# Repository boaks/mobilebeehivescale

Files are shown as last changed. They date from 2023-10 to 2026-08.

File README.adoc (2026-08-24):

// Mobile-Bienenstock-Waage, Version 2.2, Mai 2026

:imagesdir: pictures

= Mobile-Bienenstock-Waage
Achim Kraus <achim.kraus@cloudcoap.net>
v0.6, 2026-05-17

[cols="1*"]
|===
a|.Bienenstöcke mit Waage 
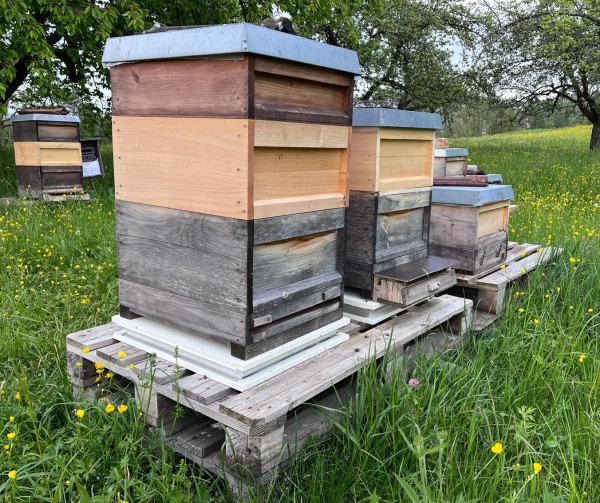
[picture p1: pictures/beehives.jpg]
Bienenstöcke mit Waage

|===

== Willkommen auf meiner Bastelanleitung für eine Mobile-Bienenstock-Waage.

Ich bin einer der IoT-Enthusiasten, der gerne echte und funktionierende Dinge baut. 2022 habe ich angefangen, einen link:https://github.com/boaks/zephyr-coaps-client[Modem-Client] zu implementieren, mit dem man zeigen kann was in link:https://cloudcoap.net[UDP] steckt. In Kombination mit link:https://github.com/eclipse-californium/californium/tree/main/demo-apps/cf-s3-proxy-server[Eclipse/Californium - CoAP-S3-Proxy] demonstriert dieses Beispiel, dass man auch von Batterie ein paar Monate/ein Jahr jede Stunde Daten austauschen kann.   

Anfang 2023 habe ich dann basierend auf diesem Modem-Client meinen erste Bienenstock-Waage gebaut und bei einem befreundeten Imker in Betrieb genommen. Das Ergebnis eines halbjährigen Testlaufs ist einfach: 

* mobiler Datenaustausch funktioniert von Batterie sehr gut
* die Waage selber hat aber viel Verbesserungspotential

Das hat dann zur einer neuen Bauart der Elektronik geführt. Die daraus entstandenen Waagen in link:README-2024.adoc[2024] zeigten dann schon, dass einiges besser ist, aber auch noch weitere Verbesserungen gut wären. Daher habe ich dann Anfang 2025 die Waagen erneut überarbeitet und nach mehreren Monaten testen gibt es nun auch zu diesem Model sehr positive Erfahrungen. Ich möchte trotzdem gleich hier einräumen, dass es genauere Waagen gibt. Mein Schwerpunkt liegt auf dem mobilen Einsatz und dem einfachen Aufbau der Elektronik.

* Es ist für die Handhabung einfacher, wenn die Steuerung/Sendbox direkt in der Waage ist. Dadurch
* gibt es kein "Kabelgewirr" (unpraktisch und teuer),
* kann man die Waagen einfacher mit den Bienenstücken umziehen, 
* bleiben die Kalibrierdaten in der Steuerung bei der Waage, zu der sie gehören.
* die verbleibenden Kabel in der Waage zu den Sensoren sind kurz, das wirkt sich positiv auf die Temperaturabweichung aus.
* Es werden 2x50kg Sensoren verwendet, anstatt 2x100kg. Das hilft nochmal die Temperaturabhängigkeit zu halbieren.
* Der Aufbau der Elektronik wurde stark vereinfacht. Es werden nun Modems verwendet, die über einen QWIIC Anschluß verfügen. So kann man den ADC NAU7802 direkt anschließen. Auch einen Solarladeregler kann man verhältnismässig einfach integrieren.

== Thingy:91X mit 2 Plattform Wägezellen

[cols="3*"]
|===
a|.2025 Waage (keine Kabel mehr!)
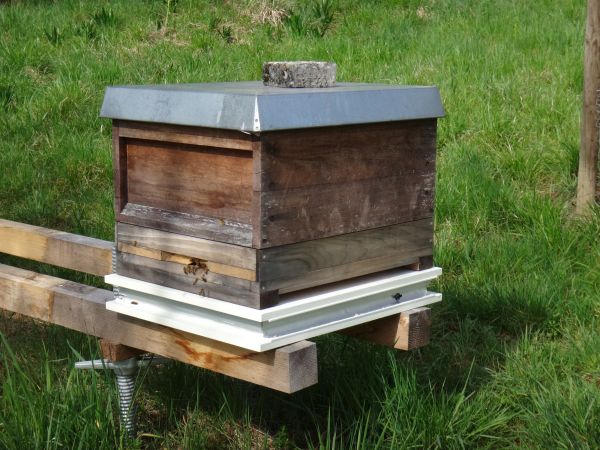
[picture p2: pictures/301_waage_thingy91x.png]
Bienenstock auf 2025 Waage (keine Kabel mehr)
 
a|.Solar-Lader (2x 1 Woche pro Jahr)
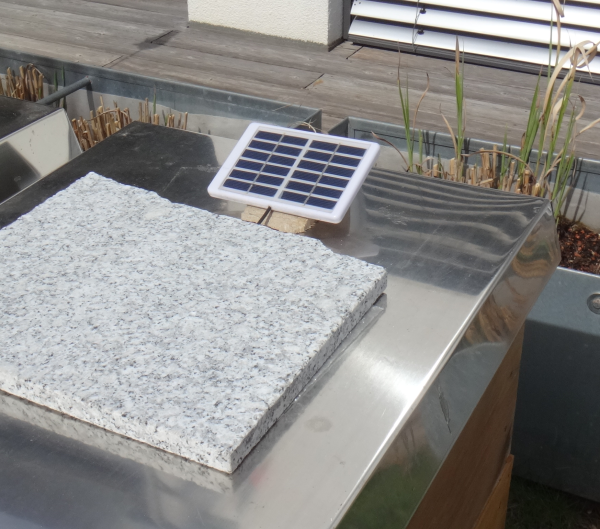
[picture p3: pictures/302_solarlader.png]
Solar-Lader (2x 1 Woche pro Jahr)

a|.Sendebox Thingy:91X und ADC
Sendebox mit Thingy:91X und ADC

a|.2025 Waage, nRF9151-feather
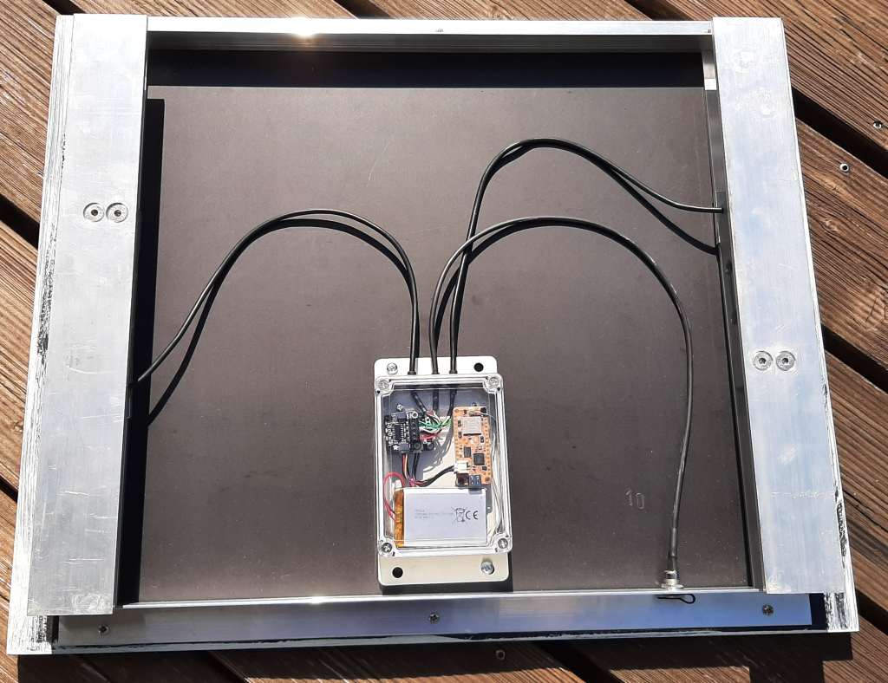
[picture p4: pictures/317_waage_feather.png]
 
a|.Sendbox mit nRF9151-feather
Sendbox mit nRF9151-feather

a|.2025 Waagendeckel für Senkkopfschrauben
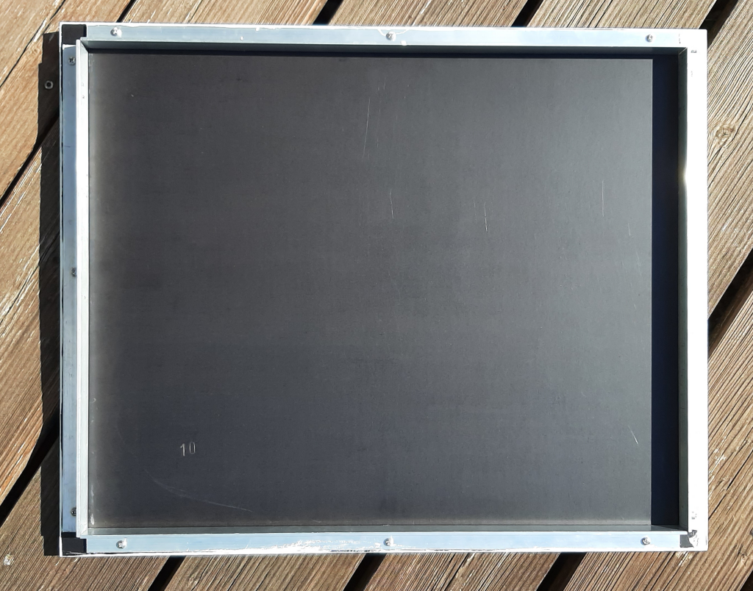
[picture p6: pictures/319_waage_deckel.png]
2025 Waagendeckel für Senkkopfschrauben


a|.Untere Platte mit Aluwinkel 5mm, Wägezellen und Thingy:91X
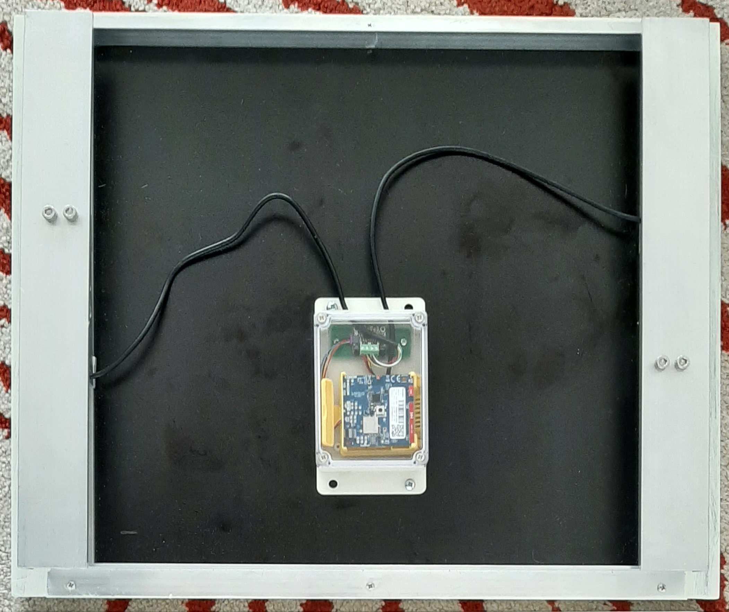
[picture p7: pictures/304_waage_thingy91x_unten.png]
Untere Platte mit Aluwinkel 5mm und Wägezellen montiert und Thingy:91X
 
a|.Schraubenköpfe
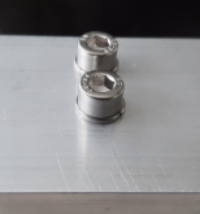
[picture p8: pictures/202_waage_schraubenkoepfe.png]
Schraubenkopf

.Verschraubung mit unterem Brett
Verschraubung 
a|.Obere Platte mit Bohrungen für Schraubenköpfe
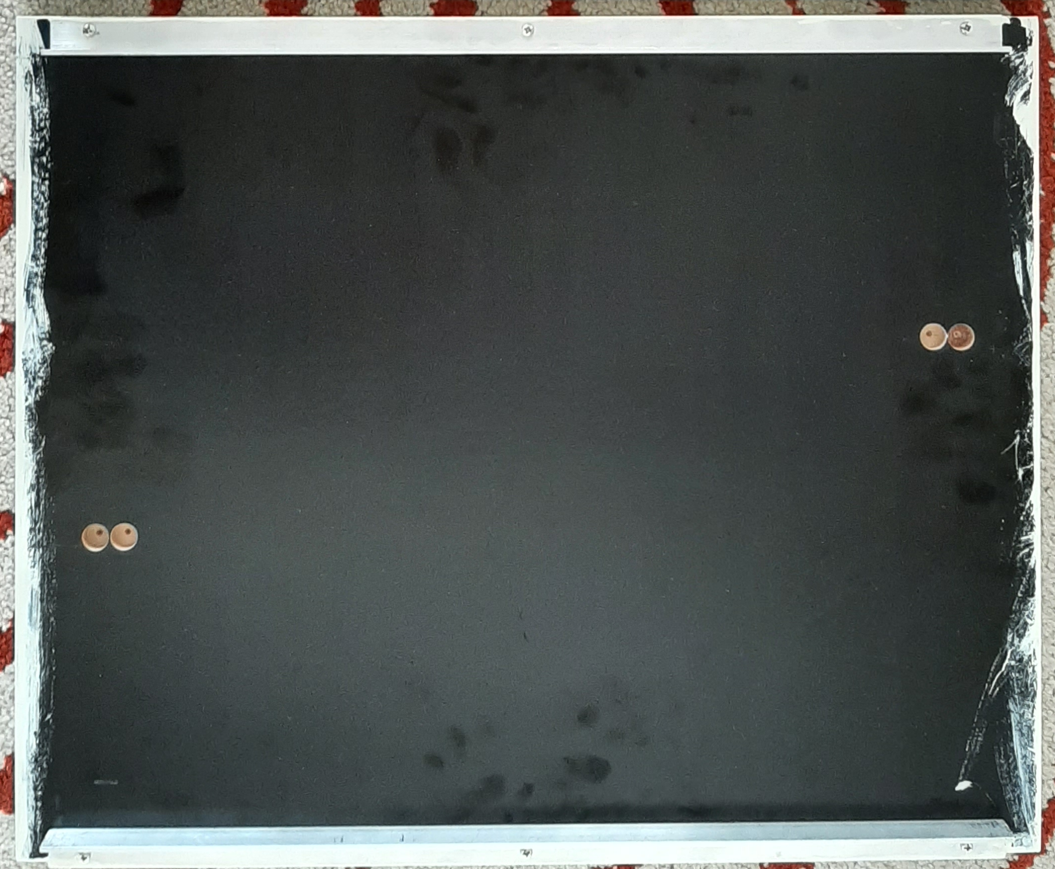
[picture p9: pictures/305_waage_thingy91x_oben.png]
Obere Platte mit Aluwinkel 3mm
 
|===

Die Version 2025 der Mobilen-Bienestock-Waage nutzt nun ein link:https://www.nordicsemi.com/Products/Development-hardware/Nordic-Thingy-91-X[Thingy:91X]. Man schliest den link:https://learn.adafruit.com/adafruit-nau7802-24-bit-adc-stemma-qt-qwiic[ADC NAU7802 von Adafruit] direkt an das Thingy:91X an und beides wandert in die Waage. Damit entfällt einiges an Verkabelung. Die Bedienung läuft über link:https://github.com/boaks/zephyr-coaps-client/blob/main/docu/CELLULAREXPLORER.md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[Bluetooth LE] und man braucht eine link:https://github.com/boaks/zephyr-coaps-client/blob/main/docu/CELLULAREXPLORER.md#smartphone-app[SmartPhone App]. Das ist aber nur für das Kalibrieren notwendig, oder wenn man testen möchte, ob die Sendebox an eimen Aufstellungsort Empfang hat.

Alternativ gibt es auch noch zwei weitere unterstütze Modems mit QWIIC, die link:https://www.circuitdojo.com/products/nrf9151-feather[nRF9151 Feather] und das link:https://conexiotech.com/conexio-stratus-pro-nrf9151/[Conexio Stratus Pro nRF9151], das letztere kommt sogar schon mit einem integrierten Solarladeregler. Beide haben aber keine Bluetooth LE Modul, so dass man ein USB Kabel für das Kalibrieren benötigt.

Der Aufbau mit 2 Plattform Wägezellen gibt der Waage ein besondere Stabilität und Unempfindlichkeit beim Aufsetzen von Lasten. Wichtig ist, dass die Wägezellen sehr schlüssig und stabil mit den starken Aluwinkeln (4mm) verschraubt werden, sonst bekommt man anstatt einer Waage eine Wippe. Die obere Siebdruckplatte wird mit kleineren Aluwinkeln (3mm) gegen verrutschen gesichert. Hier muss man darauf achten, dass diese kleineren Aluwinkel (3mm) nur an den oberen starken Aluwinkeln (4mm) anstoßt. Wenn diese auch am unteren starken Aluwinkeln (4mm) anstossen, verfälscht die Reibung das gemessene Gewicht. Daher sind die oberen zwei starken Aluwinkel (4mm) 40,0cm lang und die unteren zwei mit 39,0cm 10mm kürzer. Die kleineren Aluwinkel (2mm) für die untere Siebdruckplatten schließen den Kasten ab. Diese sind um 16mm kürzer als die oberen kleineren Aluwinkel (3mm).

Für die Schraubenköpfe der M6 Schrauben, die die starken Aluwinkel (4mm) mit der Wägezelle verbinden, muss man in die Siebdruckplatten jeweils Aussparungen bohren (siehe oben, mittleres und rechtes Bild). Die unteren starken Aluwinkeln (4mm) verschraube ich mit den 6mm Senkkopfschrauben und Muttern mit der unteren Siebdruckplatte.

Zwischen die starken Aluwinkeln (4mm) und den Plattform Wägezellen werden noch Distanzplatten benötigt, damit die Wägezelle auslenken kann.

[cols="1*"]
|===
a|.Anordung der Winkel, Distanzplatten und Wägezelle (Alu) 
Anordnung
|===

Die Anordnung der starken Aluwinkel (4mm), der Wägezelle und der Distanzplatten dazwischen habe ich so gewählt, dass der "Aufsetzschutz" (Überlastungsschutz für die Wägezelle), durch die starken Aluwinkel (4mm) selbst gegeben ist. Wichtig sind dabei das Zusammenspiel der Abmessungen. Meine Wägezelle hat eine Höhe von 22mm. Es werden dann oben und unten Distanzplatten benötigt, damit der Sensor auslenken kann. Hier benutze ich jeweils 8mm. Das ergibt dann eine Höhe von 38mm insgesamt. Meine Aluwinkel (4mm) haben eine Innenhöhe von 36mm. Somit ist die Auslenkung auf 2mm begrenzt.

Vielleicht findet der eine oder andere die Anordnung der Winkel seltsam. Ich erreiche damit zum einen nach außen (links) eine möglichst geschlossen Form zu bilden und zum anderen nach innen (rechts) offen zu sein für das Kabel, das aus der Wägezelle kommt und mit der ADC-Platine verbunden werden muss.

Das Zusammenschrauben ist einfach. Man beginnt mit den unteren starken Aluwinkel (4mm), den 8mm Distanzplatten und den Plattform Wägezellen und schraubt diese mit den Zylinderkopfschrauben und Federring fest. Die Wägezelle hat ein Richtung, die durch einen Pfeil angezeigt wird. Wenn man die Schraubenlöcher der Wägezelle benutzt, an der auch das Kabel aus der Wägezelle kommt, dann passt das. Dann schraubt man den oberen starken Aluwinkel (4mm) ebenfalls mit den 8mm Distanzplatten ebenfalls mit Zylinderkopfschrauben fest. Danach setzt man die Kombination auf die untere Siebdruckplatte und verschraubt diese mit den Senkkopfschrauben und Muttern. Ist man damit fertig, dann kann man die dünneren Aluwinkeln (2mm) seitlich ebenfalls auf der unteren Siebdruckplatte montieren. Ich nehme da Spanplattenschrauben 3,5x13mm. Zum Schluß dann noch die 4 schwächeren Aluwinkeln (3mm), oben montieren, ebenfalls mit Spanplattenschrauben.

Da Aluwinkel und Edelstahlschrauben verwendet werden, gibt es bei Nässe Korrosion. Um diese zu reduzieren benutze ich eine Isolierband zwischen den Aluwinkeln und den Siebdruckplatten.   

== Anschlußplan

[cols="3*"]
|===
a|.ADC QWIIC Verbindung 
ADC QWIIC Verbindung


a|.ADC Anschlußplan 
ADC Verkabelung
.Sensorkabel
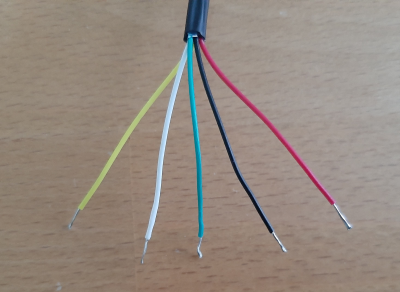
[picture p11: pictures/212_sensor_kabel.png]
Sensorkabel


a|.ADC ohne LED
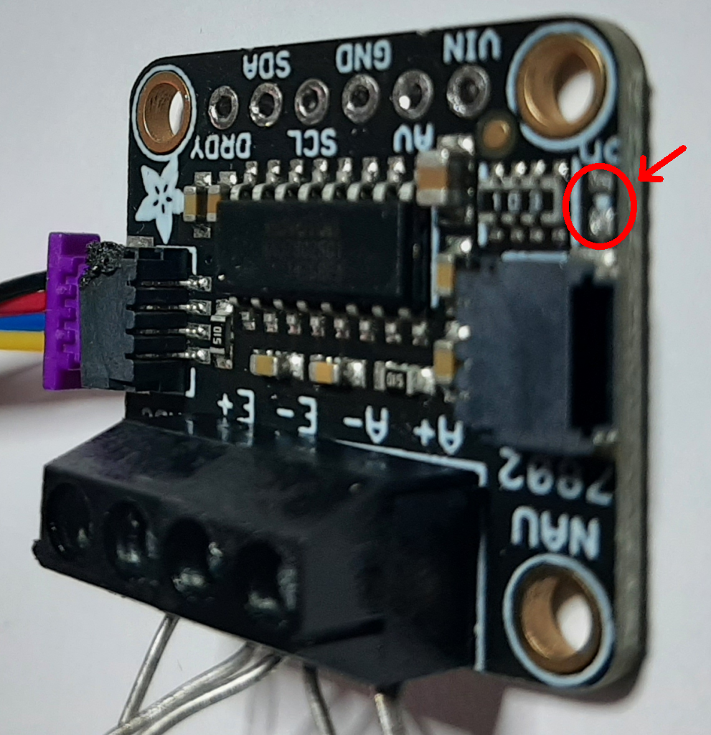
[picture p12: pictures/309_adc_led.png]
ADC ohne Power LED

|===

Der link:https://learn.adafruit.com/adafruit-nau7802-24-bit-adc-stemma-qt-qwiic[ADC NAU7802 von Adafruit] wird direkt mit einem QWIIC Kabel mit dem Thingy:91X verbunden. Auf der Rückseite der NAU7802/Adafruit Platine ist angegeben, wie man die Farben der Leitungen einer Plattform Wägezelle jeweils anschließt. Ich schliese beide Zellen parallel an, d.h. beide roten Leitungen an `E+/Red`, beide schwarzen an `E-/Black`, beide weißen an `A-/White` und beide grünen an `A+/Green`. Das erfordert etwas geschick. "Gelb" ist die Schirmleitung. Da kann man viel dazu im Web lesen. Wenn es passt, klemme ich die mit auf `E-/Black`. Ansonsten "isolieren" und schauen, ob es funktioniert.    

Die Thingy:91X Sendebox schaltet die Stromversorgung für die ADC-Platinen ab. Aktiviert werden die Sensoren dann über den internen Spannungsregler des NAU7802. Dieser liefert gemäß dem Datenblatt maximal 10mA. Für zwei Balkensensoren ist das leider zu wenig. Die brauchen je 6-8mA zusammen also mehr als 10mA. Aktuell betreibe ich solche Waagen außerhalb der Spezifikation des NAU7802. Bis jetzt funktioniert es.

Leider, leider, sind diese ADC Module aus dem Bastel/Hobby-Bereich nicht ganz für den Batteriebetrieb ausgelegt. "Power LEDs" verkürzen die Laufzeit von Batterie erheblich auf ca. 2-3 Monate, auch wenn man das ADC Modul ausschaltet, wenn es nicht benutzt wird. Wenn man die LEDs mit dem Lötkolben entfernt, dann kommt man aber auf gute 8-12 Monate, was zusammen mit zeitweisen Laden über ein Solarpanel dann sehr gut passt.
 
== Bohrpläne

Die Lage der Bohrungen bei den starken Winkeln ergibt sich, wenn der ein Winkelschenkel liegt und der andere noch ober zeigt. 

[cols="1*"]
|===
a|.oberer starker Winkel, 2x 6mm Bohrungen
Bohrplan starker Winkel Oben

a|.unterer starker Winkel, 4x 6mm Bohrungen
Bohrplan starker Winkel Unten

a|.oberer Winkel lang, 3x 3,5mm Bohrungen
Bohrplan Winkel

a|.oberer Winkel kurz, 3x 3,5mm Bohrungen
Bohrplan Winkel

a|.unterer Winkel, 3x 3,5mm Bohrungen (und 1x 11mm)
Bohrplan Aluwinkel

a|.Distanzplatten, 2x 6mm Bohrungen
Bohrplan Distanzplatten

a|.Bretter
Bohrplan Bretter
|===

== Bauteilliste

[cols="4*"]
|===
|Bauteil|Bezugsquelle|Preis (Sommer 2026)|Variante

|Thingy:91X, Nordic, LTE-M/NB-IoT nRF9151 modem  
a|link:https://www.digikey.de/en/products/detail/nordic-semiconductor-asa/THINGY91X/25650019[Thingy:91X, digikey.de]
|112,77 Euro
|Sendbox Thingy

|nRF9151-Feather,Circuit Dojo, LTE-M/NB-IoT nRF9151 modem  
a|link:https://www.digikey.de/de/products/detail/circuit-dojo/PASSY-NRF9151-FEATHER/26580618[nRF9151-Feather, digikey.de]
|69,78 Euro
|Sendbox Feather

|Akku LiPo 2000 mAh  
a|link:https://eckstein-shop.de/LiPo-Akku-Lithium-Ion-Polymer-Batterie-37V-2000mAh-mit-JST-PHR-2-Stecker-LP103450[eckstein-shop]
|7,95 Euro (zzgl. Versand)
|Sendbox Feather

|LTE Antenne  
a|link:https://www.digikey.de/de/products/detail/unictron-technologies-corporation/H2B4MH1F2F0100/9921462[nRF9151-Feather, digikey.de]
|4,42 Euro
|Sendbox Feather

|Adafruit NAU7802 24-BIT ADC, I2C
a|link:https://www.digikey.de/en/products/detail/adafruit-industries-llc/4538/16584123[Adafruit NAU7802, digikey.de]
|6,07 Euro
|Alle

|Adafruit Qwiic Kabel  
a|link:https://www.digikey.de/en/products/detail/adafruit-industries-llc/4210/10230021[Adafruit Qwiic Kabel, digikey.de]
|0,96 Euro
|Alle

|Gehäuse 115x85x35mm, Klarsichtdeckel
a|link:https://www.amazon.de/dp/B0747RGBFF?ref=ppx_yo2ov_dt_b_fed_asin_title[Gehäuse 115x85x35mm, Amazon]
|8,99 Euro
|Alle

|Gehäuse 115x85x35mm, Alternative
a|link:https://www.amazon.de/dp/B0747MHR5B?ref=ppx_yo2ov_dt_b_fed_asin_title[Gehäuse 115x85x35mm, Amazon]
|7,50 Euro
|Alle

|Gummitüllen, T-förmige, 6mm Außen x 4mm Innen x 9mm H, 3 Stück    
a|link:https://www.amazon.de/dp/B0D9K1ZNH4?ref=ppx_yo2ov_dt_b_fed_asin_title[Gummitüllen 6x4x9mm, Amazon]
|7,29 Euro (24 Stück)
|Alle

|Aluwinkel 25x50x4mm, 2x40cm (oben)
a|link:https://www.aluminium-online-shop.de/produkt-kategorie/aluminium-profile/winkel[z.B. Aluminium-Online-Shop]
|11,47 Euro (zzgl. Versand ca. 14 Euro je Bestellung)
|Alle

|Aluwinkel 40x40x4mm, 2x39cm (unten)
a|link:https://www.aluminium-online-shop.de/produkt-kategorie/aluminium-profile/winkel[z.B. Aluminium-Online-Shop]
|10,28 Euro (zzgl. Versand)
|Alle

|Aluwinkel 20x20x3mm, 2x50cm (oben)
a|link:https://www.aluminium-online-shop.de/produkt-kategorie/aluminium-profile/winkel[z.B. Aluminium-Online-Shop]
|5,16 Euro (zzgl. Versand)
|Alle

|Aluwinkel 20x20x3mm, 2x40cm (oben)
a|link:https://www.aluminium-online-shop.de/produkt-kategorie/aluminium-profile/winkel[z.B. Aluminium-Online-Shop]
|4,33 Euro (zzgl. Versand)
|Alle

|Aluwinkel 30x25x2mm, 2x48,4cm (unten)
a|link:https://www.aluminium-online-shop.de/produkt-kategorie/aluminium-profile/winkel[z.B. Aluminium-Online-Shop]
|8,33 Euro (zzgl. Versand)
|Alle

|Aluflachstange 30x8mm, für 4 Distanzplatten a 40mm Länge
a|link:https://www.aluminium-online-shop.de/produkt-kategorie/aluminium-profile/winkel[z.B. Aluminium-Online-Shop]
|5,09 Euro (zzgl. Versand)
|Alle

|Zylinderschrauben A4-80, M6 25mm, 12 Stück
a|link:https://www.schraubenhandel24.de/schrauben/gewindeschrauben/zylinderschrauben/din-912/din-912-zylinderschrauben-isk-edelstahl-a4-80/din-912-zylinderschrauben-edelsta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[z.B. Schraubenhandel24]
|15,95 Euro (200 St, zzgl. Versand)
|Alle

|Federringe A4, M6, 16 Stück
a|link:https://www.schraubenhandel24.de/scheiben/federringe/din-7980/din-7980-federringe-edelstahl-a4/ca-din-7980-a-4-federringe-fuer-zylinderschrauben-6-100st[z.B. Schraubenhandel24]
|5,68 Euro (100 St, zzgl. Versand)
|Alle

|Senkkopfschrauben A2, M6 25mm, 4 Stück
a|link:https://www.schraubenluchs.de/200-Stueck-Senkschrauben-ISO-10642-Edelstahl-A2-M-6x25[z.B. Schraubenluchs]
|6,66 Euro (200 St, zzgl. Versand)
|Alle

|Muttern A2, M6, 4 Stück
a|link:https://www.schraubenluchs.de/200-Stueck-Sechskantmuttern-DIN-934-A2-M6[z.B. Schraubenluchs]
|2,75 Euro (200 St, zzgl. Versand)
|Alle

|Spanplattenschrauben A4, 3,5x13mm, 18 Stück, 
a|link:https://www.schraubenluchs.de/1000-Stueck-Blechschrauben-DIN-7981-A4-35-x-13[z.B. Schraubenluchs]
|13,11 Euro (1000 St, zzgl. Versand)
|Alle

|Spanplattenschrauben A4, 3,5x9,5mm, 18 Stück (alternativ)
|Baumarkt
|7 Euro (50 St)
|Alle

|Plattform Wägezelle E120A 2x 50kg
a|link:https://www.vechta-waagen.com/Single-Point-Waegezelle-E120A-50-kg/VE10080[Wägezelle, Vechta-Waagen, Temperaturkompenstation]
|24,00 Euro (2x, zzgl. Versand)
|Alle

|Plattform Wägezelle CZL601 2x 50kg (alternativ, nicht mehr zu empfehlen)
a|link:https://www.tinkerforge.com/de/shop/load-cell-50kg-czl601.html[Wägezelle, Tinkerforge, Temperaturkompenstation]
|12,99 Euro (2x, zzgl. Versand)
|Alle

|Siebdruckplatten 45x55cm
|Baumarkt
|17 Euro (2x)
|Alle

|Isolierband für Aluwinkel (20mm, 25mm, 35mm)
a|link:https://www.amazon.de/dp/B0D7MGP8JT[Isolierband, Amazon]
|9,75 Euro, 12,95 Euro, 14 Euro (10m, zzgl. Versand)
|Alle

4+a|

'''

|Gesamtsumme
|
a|*260 Euro*
|
|===

(Anmerkung: leider gibt es einige Artikel nur in größeren Packungen und manches nur mit deutlichen Versandkosten. 260 Euro passen nicht, wenn man die Waage einzeln baut.) 

== Bauteilliste Solarlader

[cols="4*"]
|===
|Bauteil|Bezugsquelle|Preis (Sommer 2026)|Variante

|Adafruit BQ25185 Solar charger
a|link:https://www.digikey.de/en/products/detail/adafruit-industries-llc/6091/25805553[Adafruit BQ25185, digikey.de]
|7,10 Euro
|Alle

|Li-Ion Akku ICR18650 3.7V 2200mAh mit JST-PHR-2
a|link:https://eckstein-shop.de/PKNERGY-Lithium-Ion-Battery-ICR-18650-37V-2200mAh-LiPo-Li-Ion-with-JST-PH-Connector[eckstein-shop]
|9,48 Euro
|Sendbox Thingy

|Hohlstecker Buchse
a|link:https://www.amazon.de/dp/B0CMK6XML6[Amazon, 10er Pack]
|6,99 Euro
|Alle

|Anschlußklemme, 3 pol, 2,54 mm 
a|link:https://www.digikey.de/de/products/detail/gct/TBC05-03-1-G-G/26408859[digikey.de]
|0,99 Euro
|Alle

|Micro JST 1.0 SH 3Pin Stecker (nur für Thingy:91X)
a|link:https://www.amazon.de/dp/B0BNCG27CX[Amazon, 5er Pack]
|6,98 Euro
|Sendbox Thingy

|JST Kontakte für Buchse (nur für Thingy:91X), 2x
a|link:https://www.reichelt.de/de/de/shop/produkt/jst_-_crimpkontakt_buchse_-_xh-185091[Platinenstecker, reichelt]
|0,20 
|Sendbox Thingy

|Buchsengehäuse 2pol. (1x für Thingy:91X, 2x für andere Module)
a|link:https://www.reichelt.de/de/de/shop/produkt/jst_-_buchsengehaeuse_1x2-polig_-_xh-185085[Buchse, reichelt]
|0,06
|Alle

|JST Kabel (für andere Module)
a|link:https://www.digikey.de/de/products/detail/jst-sales-america-inc/ASPHSPH24K51/6009457[Kabel, digikey.de]
|0,30 (2x)
|Sendbox Feather

|Solarpanel (abgesetzt, Kunststoff), 6V 1.2W
a|link:https://www.amazon.de/ZONADAH-Hangable-Ladeger%C3%A4t-Projekte-Ladewerkzeuge/dp/B09CM1RJHY[(abgesetzt, Kunststoff), amazon.de]
|6,99 Euro
|Alle

|Solarpanel (abgesetzt, ALU), 5V 1.0W (alternativ)
a|link:https://www.solarversand.de/1-wp-solarmodul-mit-halterung-und-erspiess/[(abgesetzt, ALU), solarversand]
|9,95 Euro
|Alle

4+a|

'''

|Gesamtsumme
|
a|*30 Euro*
|
|===

Auch der Solarladeregler kommt mit einer "Power LED", die weg muss. Hier kommt man um den Lötkolben nicht rum

== Werkzeugliste

[cols="3*"]
|===
|Werkzeug|Bezugsquelle|Preis (Herbst 2025)

|Ständerbohrmaschine
|Sollte man schon haben, sonst wird es teuer 
|

|Spiralbohrer 3,5mm
a|link:https://www.werkzeuge-bohrer.de/bohren-in-metall-und-stahl/geschliffene-bohrer/[werkzeuge-bohrer]
|0,31 Euro

|Spiralbohrer 6mm
a|link:https://www.werkzeuge-bohrer.de/bohren-in-metall-und-stahl/geschliffene-bohrer/[werkzeuge-bohrer]
|0,83 Euro

|Spiralbohrer 8mm
a|link:https://www.werkzeuge-bohrer.de/bohren-in-metall-und-stahl/geschliffene-bohrer/[werkzeuge-bohrer]
|1,34 Euro

|Forstnerbohrer 14mm
a|link:https://www.werkzeuge-bohrer.de/bohren-in-holz/Forstner/Forstnerbohrer-10-mm-shop.html[werkzeuge-bohrer]
|3,55 Euro

|Schaftbohrer 11mm/10mm (Solarladebuchse)
a|link:https://www.werkzeuge-bohrer.de/bohren-in-metall-und-stahl/Bohrer-reduzierter-Schaft/HSS-Bohrer-aehnlich-DIN-338-Typ-NR-Schaft-10-mm.html/[werkzeuge-bohrer]
|8,36 Euro

|Versandkosten
a|link:https://www.werkzeuge-bohrer.de/[werkzeuge-bohrer]
|3,99 Euro

3+a|

'''

|Gesamtsumme
|
a|*18,37 Euro*
|===

== Arbeitszeit

Das hängt natürlich stark von der Bastel-Erfahrung ab. Ich denke, man sollte:

* 1 Nachmittag für Bestellen und Besorgen
* 1 Nachmittag für Bohren (Alu und Siebdruckplatten)
* 1 Nachmittag für Zusammenbauen und Verkabeln
* 1 Nachmittag für Fehlersuche :-)

einplanen.
 
== Software System Overview (English)

link:MobileBeehiveScale.pdf[Mobile-BeeHiveScale]

== Links

link:https://www.youtube.com/watch?v=06RcwLT99Rc[Vorstellung - Eclipse Edge of Things - (English)]

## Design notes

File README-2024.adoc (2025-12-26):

// Mobile-Bienenstock-Waage, Version 2.1, Februar 2025

:imagesdir: pictures

= Mobile-Bienenstock-Waage (2024)
Achim Kraus <achim.kraus@cloudcoap.net>
v0.5, 2025-02-16

[cols="1*"]
|===
a|.Bienenstöcke mit Waage 
Bienenstöcke mit Waage
|===

Es gibt Neuigkeiten für link:README.adoc[2025].

Willkommen auf meiner Bastelanleitung für eine Mobile-Bienenstock-Waage.

Ich bin einer der IoT-Enthusiasten, der gerne echte Dinge baut, die auch funktionieren. 2022 habe ich angefangen, einen link:https://github.com/boaks/zephyr-coaps-client[Modem-Client] zu implementieren, mit dem man zeigen kann was in link:https://cloudcoap.net[UDP] steckt. In Kombination mit link:https://github.com/eclipse-californium/californium/tree/main/demo-apps/cf-s3-proxy-server[Eclipse/Californium - CoAP-S3-Proxy] demonstriert dieses Beispiel, dass man auch von Batterie ein paar Monate jede Stunde Daten austauschen kann.   

Anfang 2023 habe ich dann basierend auf diesem Modem-Client meinen erste Bienenstock-Waage gebaut und bei einem befreundeten Imker in Betrieb genommen. Das Ergebnis des halbjährigen Testlaufs ist einfach: 

* mobiler Datenaustausch funktioniert von Batterie sehr gut
* die Waage selber hat aber viel Verbesserungspotential

Das hat dann zur einer neuen Bauart der Elektronik geführt. Ich möchte gleich hier einräumen, dass es genauere Waagen gibt. Mein Schwerpunkt liegt auf dem mobilen Einsatz und dem Aufbau der Elektronik.

* ADC wandert aus der Sendebox unter die Waage. Kurze Kabel zu den Dehnmesstreifen sind wichtig für eine geringere Temperaturabhängigkeit.
* Kalibrierungsdaten müssen ebenfalls in die Waage. Sonst ist es sehr fehleranfällig, wenn die Waagen umziehen und vertauscht werden. Neu Kalibrieren ist auch einfacher, da man das dann mit jeder Sendbox durchführen kann und nicht die nehmen muss, mit der man dann die Waage im Feld wirklich betreibt.

Die neue Bauart berücksichtigte beides zusammen und läuft nun seit ein Herbst 2023 auf meiner Terrasse und seit Frühjahr 2024 unter Bienenstöcke. Daher möchte ich hier dieses Ergebnis präsentieren, vielleicht hat ja der eine oder andere Interesse, diese Mobile-Bienenstock-Waage nachzubauen. Leider ist aber das Bauen der 2-Kanal-Sendebox doch aufwendig. Seit Winter 2024 gibt es ein neues Gerät von Nordic, das link:https://www.nordicsemi.com/Products/Development-hardware/Nordic-Thingy-91-X[Thingy:91X], welches nun über einen Qwiic (I2C) Port verfügt. Damit kann man den Aufbau drastisch vereinfachen: man steckt den ADC NAU7802 direkt an das Thingy:91X, kein Löten mehr. Verglichen mit der 2-Kanalbox (200 Euro), sind die Kosten mit 130 Euro etwas höher, man braucht ja 2. Wer sich dafür interessiert, liest am besten bei link:T91XDOUBLESCALE.adoc[Waage mit Thingy:91X + NAU7802] weiter. 

Die Ausführung ist ein Kompromis. Manches beruht darauf, was man aus bestehende Komponeten machen kann. Man kann sich da auch alternative Ausführungen vorstellen, aber da bräuchte man dann andere Komponenten oder müßte die selber erstellen. Vielleicht kommt ja die eine oder andere Verbesserung mit der Zeit. 

Links zu den Open Source Projekten:

link:https://github.com/boaks/zephyr-coaps-client[Modem-Client - https://github.com/boaks/zephyr-coaps-client]

link:https://github.com/eclipse-californium/californium/tree/main/demo-apps/cf-s3-proxy-server[Eclipse/Californium - CoAP-S3-Proxy - https://github.com/eclipse-californium/californium/tree/main/demo-apps/cf-s3-proxy-server]

== Bausteine

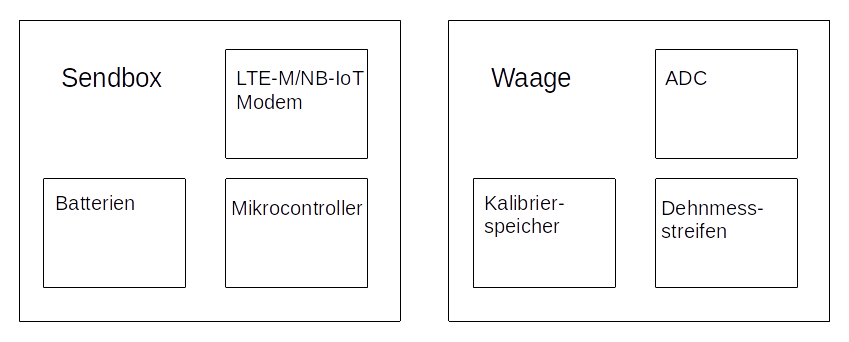
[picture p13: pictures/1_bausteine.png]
Bausteine


Die Mobile-Bienenstock-Waage besteht aus einer `Sendbox` und der `Waage` selbst. 

In der `Sendbox` sind das LTE-M/NB-IoT Modem, der Mikrocontroller und die Batterien untergebracht. Ich benutze ein link:https://www.nordicsemi.com/products/nrf9160[nRF9160] als link:https://www.jaredwolff.com/store/nrf9160-feather/[nRF9160 feather]. Dieses Modem hat als Besonderheit bereits eine Mikrocontroller auf dem Modul, ein ARM Cortec M33 mit 1 mByte Flash und 256 kByte RAM. Als Batterien benutze ich gerne NiMh mit geringer Selbstentladung.

Die Elektronik der `Waage` besteht dann aus einem `ADC`, einem `Speicher für die Kalibrierdaten`, den `Dehnmessstreifen` (als fertige Sensoren). Und natürlich dem mechanischen Aufbau, der aber wie eingangs schon erwähnt, nicht der Schwerpunkt dieser Bastelanleitung ist.

== Der I2C ADC Wandler mit EEPROM

[cols="2*"]
|===
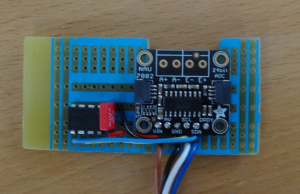
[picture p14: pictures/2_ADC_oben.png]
ADC von oben
a| 
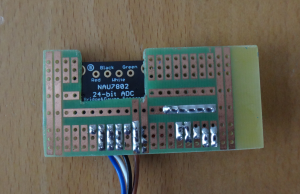
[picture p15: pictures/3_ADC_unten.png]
ADC von unten
a|
|===

Um sowohl den `ADC` als auch den `Kalibrierspeicher` unter die `Waage` zu packen, sollten beide die gleiche Schnittstelle haben. Daher habe ich den geläufigen HX711 gegen einen link:https://www.nuvoton.com/products/smart-home-audio/audio-converters/precision-adc-series/nau7802kgi/[NAU7802] mit link:https://de.wikipedia.org/wiki/I%C2%B2C[I2C] getauscht und ein kleines link:https://www.microchip.com/en-us/product/at24hc04b[AT24HC04B EEPROM], ebenfalls mit `I2C`, hinzugepackt.

Um den NAU7802 nicht selber auf eine Platine packen zu müssen, habe ich ein link:https://learn.adafruit.com/adafruit-nau7802-24-bit-adc-stemma-qt-qwiic[fertiges Modul von Adafruit] benutzt. Das muss dann zusammen mit dem EEPROM auf eine zusätzliche kleine Platine, bei mir passt das auf 5x3cm. Die Verkabelung ist sehr einfach, man muss die Stromversorgung an beide ICs anlegen und die beide I2C Leitungen, SDA und SCL jeweils mit dem anderen IC verbinden. Als Kabel zur Sendebox habe ich ein 4 poliges Kabel, 2m, mit einem 12mm Stecker (eigentlich Buchse) und einem offenen Kabelende genommen, z.B. link:https://www.lutronic.biz/de/konnektivitaet/produkt/1200+...+0[Lutronic M12].

Das link:https://learn.adafruit.com/adafruit-nau7802-24-bit-adc-stemma-qt-qwiic[NAU7802 von Adafruit] hat eine LED die anzeigt, dass die Stromversorgung anliegt. Da sowohl der NAU7802 als auch das EEPROM aber einen sehr geringen Ruhestrom haben, schalte ich den Strom nicht ab. Ich habe daher die LED entfernt, damit diese nicht unnötig den Ruhestrom vergrößert.  

|===
|Beschreibung|NAU7802|AT24HC04B|Kabel Lutronic

|Vcc
|Vin
|Vcc, PIN 8
|Braun

|GND
|GND
|GND, PIN 4
|Schwarz

|SDA
|SDA
|SDA, PIN 5
|Blau

|SCL
|SCL
|SCl, PIN 6
|Weiß
|===

Der Anschluß `AV` (Analog Vin) des NAU7802 wird nicht benutzt, wir benutzen den internen Spannungsregler des NAU7802.

Beim EEPROM bleiben `WP` (Write Protect, PIN 7) soweit `A1` und `A2` (PIN 2 und PIN 3) unbeschaltet bzw. diese können mit `GND` verbunden werden.
Für das EEPROM habe ich den üblichen 0,100 µF Folienkondensator zwischen `GND` und `Vcc` zur Entkopplung benutzt. 

Der DMS Sensor muss dann noch entsprechend mit ``E+``/``E-``/``A+``/``A-`` des NAU7802 verbunden werden. Man kann dazu entweder die beim Adafruit mitgelieferten Schraubklemmen benutzen oder die Leitungen anlöten. Die genau Verdrahtung ist weiter unten in <<die-waage>> beschrieben. Wenn alles gelötet ist sorgfälltig alle Flußmittelreste mit einem Reiniger entfernen. Wenn ich Platinen im Freien nutze, versehe ich diese mit einem Schutzlack. Auch wenn diese natürlich in ein Gehäuse kommt.

Der interne Spannungsregler des NAU7802 liefert gemäß dem Datenblatt maximal 10mA. Das passt für viele Sensoren, nicht aber wenn zwei Balkensensoren verbaut werden. Die brauchen je 6-8mA zusammen also mehr als 10mA. Aktuell betreibe ich solche Waagen außerhalb der Spezifikation des NAU7802. Vielleicht funktioniert es ja, wenn man nur alle Stunde für ein paar Sekunden anschaltet. 

Wenn nicht, braucht man für diesen Fall einen externen Spanungsregler mit `ENable` Eingang, z.B. link:https://www.ti.com/lit/ds/symlink/lp2980-n.pdf[LP2980-N]. `E+` muss dann dort mit den `ENable` (On/OFF PIN 3) verbunden werden und `E+` der Sensoren mit dem Ausgang des Spannungsreglers. Man muss auch die Empfehlungen für zusätzlich Kondensatoren beachten, meist 1µF low ESR und 0,1µF Folienkondensator. Und man muss auch auf eine "low drop" Version achten. `Vcc` beträgt nur 3,3V und am Sensor sollte man 2,7-3,0V haben. Leider ist bei der Adafruit Version der Eingang für `REFP` nicht nutzbar, damit geht dann die ratiometrische Beschaltung des ADC-Boards verloren, wenn man den externen Spanungsregler über `E+` schalten möchte. Die ratiometrische Beschaltung sorgt sonst dafür, dass langsame Abweichungen in der analogen Spannung das Messergebnis nicht beeinflußen.

Die 3,3V Versorgungsspannung ist ein Kompromis. Wenn man auf 5V hoch geht, dann sind die Messergebnisse genauer. Aber dazu muss man aus den Batterien diese zweite 5V Spannung ableiten, und das mit möglichst geringem Ruhestrom. Oder 4 anstatt 3 AA Batterien nehmen. Ich habe mich erst einmal für die einfache Variante mit 3,3V entschieden.

Anmerkung: leider stellte sich raus, dass das link:https://www.microchip.com/en-us/product/at24hc04b[AT24HC04B EEPROM] einen I2C Adress-Konflikt mit dem auf der link:https://www.jaredwolff.com/store/nrf9160-feather/[nRF9160 feather] verbauten Uhrenchip hat. Wenn man die oberen 256 Bytes des EEPROM anspricht, dann wird aus der 0x50 I2C Adresse des EEPROM die 0x51 was aber die des link:https://www.nxp.com/products/analog-and-mixed-signal/real-time-clocks/rtcs-with-ic-bus/tiny-real-time-clock-calendar-with-alarm-function-and-ic-bus:PCF85063A[PCF85063A I2C clock] ist. Daher werden nun nur die unteren 256 Bytes genutzt.

Ich empfehle, die Kabellänge auch nicht länger als 2m (eher kürzer) zu wählen. Ansonsten empfiehlt es sich, die 10k Ohm I2C Pull-up Widerstände des link:https://learn.adafruit.com/adafruit-nau7802-24-bit-adc-stemma-qt-qwiic[NAU7802 Modul von Adafruit] mit zusätzlichen 4,7k Ohm Widerständen auf der Platine zu verringern. Aber auch damit kann man keine 5m betreiben.

== Die Platine der Sendebox

[cols="2*"]
|===
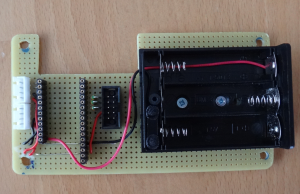
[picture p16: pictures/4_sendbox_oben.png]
Sendbox-Platine von oben
a| 
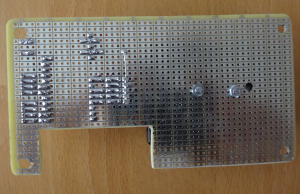
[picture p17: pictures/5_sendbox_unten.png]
Sendbox-Platine von unten
a|
|===

Die zwei Hauptkomponenten, die auf diese Platine müssen, sind die link:https://www.jaredwolff.com/store/nrf9160-feather/[nRF9160 feather] und das Batterienfach, hier 3x AA. Die Verkabelung der Batterei ist trivial und auch die für die link:https://www.jaredwolff.com/store/nrf9160-feather/[nRF9160 feather] ist relativ einfach. Sie besteht aus der Stromversorgung von der Batterie, der Stromversorgung und I2C Bus zu den ADC Platinen, einer RGB LED sowie einem Taster. Die Platine unterstützt bis zu zwei Waagen, jede an einem eigenen I2C Bus (das ist beim NAU7802 leider notwendig). Die beiden I2C sind auf zwei 4 pol. Platinenstecker gelegt. Der Taster und die RGB LED auf einen 10 pol. Pfostenstecker. Die Aussparung in der Platine braucht man, um diese in der Box an der RGB LED und dem Taster vorbei aus- und einbauen zu können. Die verwendete Box hat die Abmessungen 160x80x55mm und erfüllt IP66. Wenn man eine andere Box benutzen möchte, muss man aufpassen, dass die beiden I2C Einbaustecker, die RGB-LED und der Taster entsprechend montiert werden können.

Die Platine muss entsprechend von 160x100mm auf 132x72mm zurecht gesägt werden. Die Aussparung mit 45x20mm wird benötige, da die Platine u.U. bei eingebauter LED und den Taster noch ausgebaut werden muss. Die Bohrungen für die Schrauben haben einen Durchmesser von 4,5mm. Bei den Schrauben muss man auch besonders auf die Länge aufpassen. Bei den Blechschrauben mit Durchmesser 4,2mm ist die Länge 9,5 gängig. Leider sind bei meinem Gehäuse die Bohrungen nur 6mm tief. 2mm für die Platine, dann steht die Schraube 1,5mm über ... das führt zu leicht dazu, dass es ein kleines Loch am Gehäuseboden gibt.

[cols="1*"]
|===
a|.Bohrplan Platine 
Bohrplan
|===

|===
|Beschreibung|nRF9160 feather|Komponente

3+a|*Stromversorgung*

|Vin
|BAT, J2 / PIN 1 
|+ Batterie

|GND
|GND, J3 / PIN 4
|- Batterie

3+a|*I2C Schnitstelle zu ADC-1 über 4 pol. Platinenstecker*

|Vcc
|+3V3, J3 / PIN 2
|ADC 1, Vin, PIN 4

|GND
|GND, J3 / PIN 4
|ADC 1, GND, PIN 3

|SDA 1
|SDA 1, J2 / PIN 12
|ADC 1, PIN 1

|SCL 1
|SCL 1, J2 / PIN 11
|ADC 1, PIN 2

3+a|*I2C Schnitstelle zu ADC-2 über 4 pol. Platinenstecker*

|Vcc
|+3V3, J3 / PIN 2
|ADC 2, Vin, PIN 4

|GND
|GND, J3 / PIN 4
|ADC 2, GND, PIN 3

|SDA 2
|SDA 2, J2 / PIN 7
|ADC 2, PIN 1

|SCL 2
|SCL 2, J2 / PIN 6
|ADC 2, PIN 2

3+a|*10 pol. Pfostenstecker*

|GND
|GND, J3 / PIN 4
|Pfostenstecker, PIN 1,3,5,7,9

|Vcc
|+3V3, J3 / PIN 2
|Pfostenstecker, PIN 4

|Taster
|P0.17, J3 / PIN 9
|Pfostenstecker, PIN 2

|LED Rot
|P0.19, J3 / PIN 11
|Pfostenstecker, PIN 6, 380 Ohm

|LED Blau
|P0.21, J3 / PIN 12
|Pfostenstecker, PIN 8, 380 Ohm

|LED Grün
|P0.22, J3 / PIN 13
|Pfostenstecker, PIN 10, 380 Ohm
|===

Wenn man eine link:https://www.reichelt.de/laborkarte-cem3-rm-2-54-mm-3-loch-loetinseln-re-310-s1-p105479.html[3-Loch-Lötinseln] Platine nimmt, dann ist der Aufbau meist mit einfachen Drahtbrücken zwischen den Lötinseln machbar.

[cols="2,1,1,1"]
|===
|"Löten nach Farben"|Beschreibung|Farbe|Bemerkung

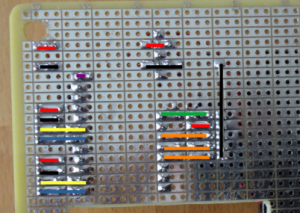
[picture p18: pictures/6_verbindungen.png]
1.7+a|
|Vin
|Lila
|

|GND
|Schwarz
|Auch Oberseite

|Vcc
|Rot
|Auch Oberseite

|SDA
|Blau
|

|SCL
|Gelb
|

|Taster
|Grün
|

|RGB LED
|Orange
|380 Ohm
|===

Die I2C Signalleitungen sind einfache Drahtbrücken zwischen 4 pol. Platinenstecker und Feather. Ebenso die Verbindung für den Taster zum 10 pol. Pfostenstecker. Die Verbindung für die LEDs zum 10 pol. Pfostenstecker und Feather macht man am einfachsten mit den 380 Ohm Vorwiderständen. Die Kabel des Batterienhalter kann auch man einfach mit der Feather verbinden. Mit `Vcc` und `GND` ist es nicht ganz so einfach, da müssen die Inseln auch auf der Oberseite der Platine entsprechend verbunden werden. Ich habe dazu meist farbige Kabellitzen benutzt. Nur für `GND` zum 10 pol. Pfostenstecker auf der Unterseite habe ich auch Draht genommen. 

Die RGB LED und der Taster werden dann über ein Flachkabel angelötet und über eine Pfostenbuchse angesteckt. Dabei wird der Taster mit `GND` und `PIN 2` verbunden. Die gemeinsame Anode (+) der RGB LED wird mit `PIN 4` verbunden, die jeweiligen Farb-Kathoden mit `PIN 6`, `PIN 8` und `PIN 10`. Das fertige Kabel kann man weiter unten bei <<die-sendebox>> sehen.

Die zwei externen I2C Busse direkt an der nRF9160 Feather anzuschließen ist auch ein Kompromis. Ein zusätzlicher link:https://www.sparkfun.com/products/16784[I2C Multiplexer] wäre hier ein bessere Lösung aber man muss da noch einiges in der Software anpassen und testen, so das ich mich ebenfalls für die einfachere Ausführung ohne diesen `I2C Multiplexer` entschieden habe. 

== Die Waage

ifdef::env-github[]
[cols="2*"]
|===
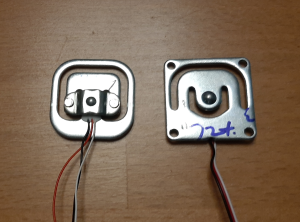
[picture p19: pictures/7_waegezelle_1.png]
Einfache Wägezelle
a| 
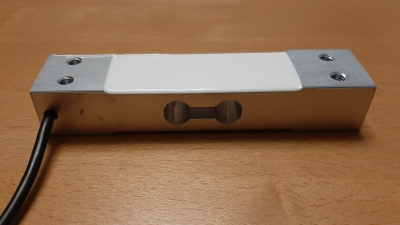
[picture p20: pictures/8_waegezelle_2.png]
Plattform Wägezelle
a| 
|===
endif::[]

ifndef::env-github[]
[cols="2*"]
|===
a|Einfache Wägezelle 
a|Plattform Wägezelle 
|===
endif::[]

Waagen kann man auf unterschiedlichste Weisen bauen. Man findet dazu auf den entsprechenden Internetseiten viele Anregungen.

Ich selber habe mich mit zwei Bauarten versucht:

Links eine sehr link:SIMPLESCALE.adoc[einfache Waage] mit 4x Halbbrücken Wägezellen für je 50Kg. Diese Wägezellen werden normalerweise für Personenwaagen benutzt. Insgesamt ein kosten günstiger Einstieg, mit begrenzter Haltbarkeit und das Gewicht ist deutlich Temperaturabhängigkeit.

Rechts eine link:DOUBLESCALE.adoc[aufwendigere Waage] mit 2x Plattform Wägezellen für je 100Kg. Der Aufbau ist aufwendiger und deutlich teurer, liefert dafür das genauere Gewicht, besonders im Bezug auf die Temperaturabhängigkeit der Wägezellen.
  
== Das Modem

[cols="2*"]
|===
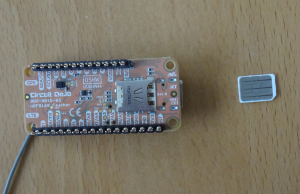
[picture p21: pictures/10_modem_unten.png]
Modem von unten
a| 
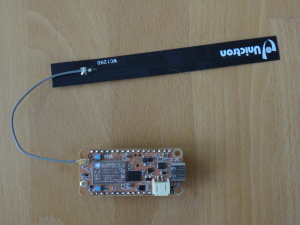
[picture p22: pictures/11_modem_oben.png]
Modem von oben
a| 
|===

Wie eingangs schon erwähnt, die Besonderheit dieses link:https://www.nordicsemi.com/products/nrf9160[nRF9160 Modems] ist, dass es bereits eine Mikrocontroller enthält. Damit spart man sich viel Bastelarbeit. Und als link:https://www.jaredwolff.com/store/nrf9160-feather/[nRF9160 feather] geht das Basteln leicht von der Hand. Für den Mobilfunk benötigt man dann ein SIM-Karte. Normale SIM-Karten sind nicht für LTE-M oder NB-IoT freigeschalten, man muss entsprechende IoT SIM-Karten benutzen. Leider sind diese oft nur für Gewerbebetreibende erhältlich. Die Kosten reichen von 1 Euro pro Jahr über 70 Cent pro Monat bis auch 5 Euro pro Monat. Das hängt ganz vom Anbieter ab. Die Waage mit link:https://www.rfc-editor.org/rfc/rfc7252.html[CoAP] / link:https://www.rfc-editor.org/rfc/rfc6347.html[DTLS 1.2] link:https://www.rfc-editor.org/rfc/rfc9146.html[CID] benötigt sehr wenig Datenvolumen. Wenn man das Gewicht von 2 Waagen alle Stunde sendet sind das ca. 700 kByte im Monat. Viel der Karten bieten 50 MByte pro jahr an und kommen dann damit locker hin. Die 3 AA 2000mAh Akkus halten 6-12 Monate. Das hängt von vielen Faktoren ab, auch wie die SIM-Karten vom Provider konfiguriert sind und welche Netze erlaubt sind.

Das Modem unterstützt auch andere Protokolle, z.B. `HTTP(S)` oder `MQTT(S)`. Je nach Sende-Strategie benötigen diese deutlich mehr Energie oder übertragen die Daten sehr viel seltener (z.B. 1x Täglich nicht 1x Stündlich). Ich benutze diese daher nicht. Wer selber programmieren kann, kann das aber sehr gerne ausprobieren. 

Man kann die Daten auch weiterleiten, das link:https://github.com/eclipse-californium/californium/tree/main/demo-apps/cf-s3-proxy-server[Eclipse/Californium - CoAP-S3-Proxy] leited diese z.B in einen `S3` Cloudservice weiter. Die aktuelle Web-Browser App liest die Daten dann dort aus und stellt diese als Chart dar.

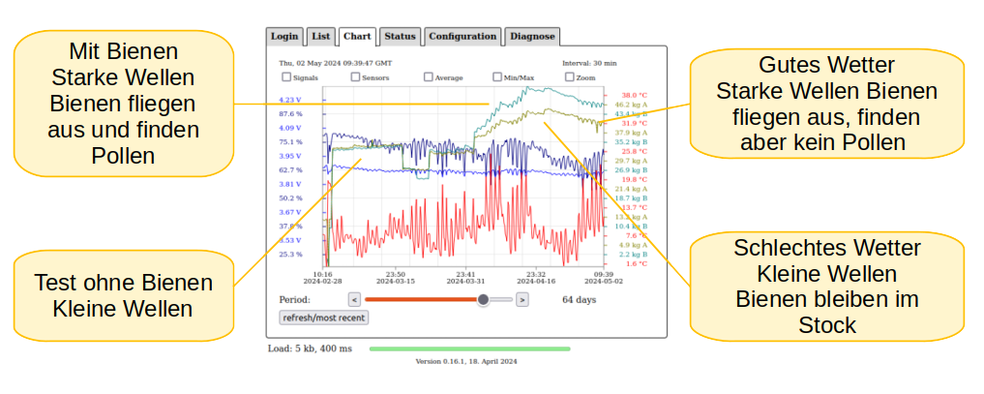
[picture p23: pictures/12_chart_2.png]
Chart im Web-Browser
  

Man muss klar erwähnen, dass es auch bei LTE-M und NB-IoT Funklöcher gibt, also Orte, wo der Empfang schlecht ist oder kein Empfang möglich ist. Wenn man sich die Enttäuschung die Waage vergeblich aufzustellen sparen will, kann mit einem link:https://www.nordicsemi.com/Products/Development-hardware/Nordic-Thingy-91[Thingy:91] und einem Android Smart Phone auch vorab testen, ob man Empfang hat und welche Signalstärke man bekommt. Dazu habe ich ebenfalls ein Programm entwickelt, den link:https://github.com/boaks/zephyr-coaps-client/blob/main/docu/CELLULAREXPLORER.md[Cellular Explorer] mit dem man die Netzwerklandschaft erkunden kann.
 
Der Applikations Mikrocontroller des nRF9160 wird in C programmmiert. Das Embedded Betriebssystem ist link:https://www.zephyrproject.org/[Zephyr]. Die Applikation für die Waage findet man in meinem link:https://github.com/boaks/zephyr-coaps-client[Zephyr - CoAPs Demo Client]. Näheres zur Konfiguration kann man dann dort in link:https://github.com/boaks/zephyr-coaps-client/blob/main/docu/MOBILEBEEHIVESCALE.md/[Mobile-Beehive-Scale]. Die Applikation ist bzgl. der Waage eher eine Entwicklungsversion als eine stabile Release.

Die Bedienung und Anzeige ist relativ einfach.

|===
|Aktion|Funktion 

2+a|*Normalbetrieb*

|Taster kurz drücken und loslassen ( < 5s)
|Gewichte mit der Waagen ermitteln und senden. +
Die LED wird blau und dann hellblau. Sobald sie grün wird hat das Modem Empfang. Blinkt es danach rot, trat ein Fehler auf. Blinkt es lila sucht das Modem ein Funknetzwerk. 

|Taster lang drücken ( > 5s)
|Setupbetrieb

2+a|*Setupbetrieb*
2+|Die Farbe wechselt alle 5s zwischen Grün und Blau

|Taste bei Grün kurz drücken ( < 5s)
|Kalibrierbetrieb

|Taste bei Blau kurz drücken ( < 5s)
|Sendbox neu starten

|Taste lange drücken ( > 5s)
|Setupbetrieb verlassen, in den Normalbetrieb wechseln 

2+a|*Kalibrierbetrieb*
2+|Die Kalibrierung erfolgt in 6 Schritten.
|LED blink grün|Vorbereitung beide Waage für die 0kg-Punkt Kalibrierung
|LED grün|Beide Waage kalibrieren den 0kg-Punkt
|LED blink blau|Vorbereitung Waage 1 für die 10kg Kalibrierung 
|LED blau|Waage 1 kalibriert 10kg
|LED blink hellblau|Vorbereitung Waage 2 für die 10kg Kalibrierung
|LED hellblau|Waage 2 kalibriert 10kg
2+|Ist Waage 1 oder 2 nicht angeschlossen, entfällt der Schritt.

2+|In den Vorbereitungsschritten mit blinkender LED wartet die
Applikation auf einen Tastendruck um dann die jeweilige Kalibrierung durchzuführen.

|Taste kurz drücken ( < 5s)
|Kalibrierung duchführen. +
Wechsel zum nächsten Vorbereitungschritt. Am Ende speichern und in den Normalbetrieb wechseln 

|Taste lang drücken ( > 5s)
|Kalibrierung abbrechen, speichern und in den Normalbetrieb wechseln 
|===

== Die Sendebox

[cols="3*"]
|===
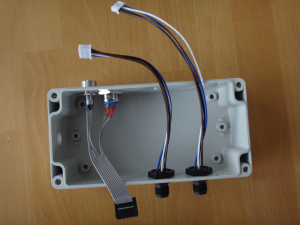
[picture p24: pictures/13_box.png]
Sendebox leer
a| 
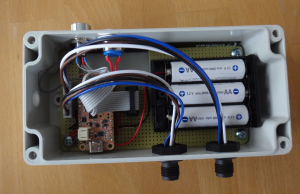
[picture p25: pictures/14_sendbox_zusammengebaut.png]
Sendbox zusammengebaut
a|
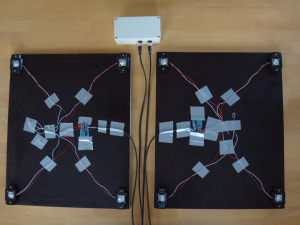
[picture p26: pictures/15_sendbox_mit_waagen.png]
Sendbox mit Waagen
a|
|===

Das erste Bild zeigt die leere Sendebox mit den 2 Kabeln für die ADCs/I2C und dem entsprechenden Einbaustecker für die 12mm Kabel. Das Flachbandkabel für die RGB-LED und den Taster sieht man ebenso. Im zweiten Bild sieht man, wie es aussieht, wenn die Platine, das Modem und die Sendbox zusammengebaut sind. Beim Battereienfach ist es besser eines mit Deckel zu nehmen. Den muss man dann noch schließen bevor man den Deckel der Box ebenfalls schließt. Das letzte Bild zeigt dann, wie zwei Waagen angeschloßen werden.

Wenn man das 160x80x55mm Gehäuse aus der <<Bauteilliste>> nimmt, und auch die Stecker, den Taster und das LED Gehäuse, dann benötigt man 2x 16mm Bohrungen für die Stecker, 1x 16mm für den Taster und 1x 8mm für das LED Gehäuse.

[cols="2*"]
|===
a|.Bohrplan Vorderseite LED und Taster 
Bohrplan

a|.Bohrplan Rückseite für Stecker 
Bohrplan

|===

Die 16mm Bohrungen waren für mich die schwersten. Ich habe mit einem Kegelbohrer die besten Ergebnisse. Ich habe den bei 16mm mit einem Filzstift marktiert und dann mit der Ständerbohrmaschine gebohrt. Das letzte kleine bischen habe ich dann mit den Kegelbohrer von der anderen Seite mit Hand aufgebohrt. Damit passen dann die Dichtungen der Stecker und des Taster gut in das Loch.

== Arbeitszeit

Das hängt natürlich stark von der Bastel-Erfahrung ab. Ich denke, man sollte:

* 1 Nachmittag für Bestellen und Besorgen
* 1 Nachmittag für Waage und ADC Platine
* 1 Nachmittag für Sendbox, Platine und Gehäusebearbeitung
* 1 Nachmittag für Fehlersuche :-)

einplanen.
 
== Bauteilliste

Eine Liste mit Vorschlägen für die verwendeten Bauteilen und deren Bezugsquellen habe ich auch erstellt.
Es gibt bei den einzelnen Bauteilen Alternativen und alternative Bezugsquellen.

ifdef::env-github[]
link:BAUTEILLISTE.adoc[Bauteilliste]
endif::[]

ifndef::env-github[]
link:BAUTEILLISTE.html[Bauteilliste]
endif::[]

== Software System Overview (English)

link:MobileBeehiveScale.pdf[Mobile-BeeHiveScale]

== Links

link:https://www.youtube.com/watch?v=06RcwLT99Rc[Vorstellung - Eclipse Edge of Things - (English)]

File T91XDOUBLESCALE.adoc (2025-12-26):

// Mobile-Bienenstock-Waage, Version 2.1, Februar 2025

:imagesdir: pictures

= Mobile-Bienenstock-Waage
Achim Kraus <achim.kraus@cloudcoap.net>
v0.5, 2024-05-07

== Thingy:91X mit 2 Plattform Wägezellen

[cols="3*"]
|===
a|.Thingy:91X Waage (keine Kabel mehr!)
Bienenstock auf Thingy:91X-Waage (keine Kabel mehr) 
a|.Solar-Lader (2x 1 Woche pro Jahr)
Solar-Lader (2x 1 Woche pro Jahr)
a|.Sendebox Thingy:91X
Sendebox mit Thingy:91X

a|.Untere Platte mit Aluwinkel 5mm, Wägezellen und Thingy:91X
Untere Platte mit Aluwinkel 5mm und Wägezellen montiert und Thingy:91X 
a|.Schraubenköpfe
Schraubenkopf Schraubenkopf
.Verschraubung mit unterem Brett
Verschraubung 
a|.Obere Platte mit Bohrungen für Schraubenköpfe
Obere Platte mit Aluwinkel 3mm 
|===

Die neuste Version (2025) der Mobilen-Bienestock-Waage nutzt nun ein link:https://www.nordicsemi.com/Products/Development-hardware/Nordic-Thingy-91-X[Thingy:91X] und einen deutlich vereinfachten Aufbau der Elektronik. Man schliest den link:https://learn.adafruit.com/adafruit-nau7802-24-bit-adc-stemma-qt-qwiic[ADC NAU7802 von Adafruit] direct an das Thingy:91X und beides wandert in die Waage. Damit entfallt einiges an Verkabelung. Die Bedienung läuft dann über link:https://github.com/boaks/zephyr-coaps-client/blob/main/docu/CELLULAREXPLORER.md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[Bluetooth LE] und man braucht eine link:https://github.com/boaks/zephyr-coaps-client/blob/main/docu/CELLULAREXPLORER.md#smartphone-app[SmartPhone App]. Das ist aber nur für das Kalibrieren notwendig, oder wenn man testen möchte, ob die Sendebox an eimen Aufstellungsort Empfang hat.

Die Waage ist mit 2x Plattform Wägezellen aufgebaut und entspricht dem vorherigen Model für eine link:DOUBLESCALE.adoc[aufwendigere Waage]. Man kann nur 1 Waage pro Thingy:91X anschließen. Der Aufbau ist leicht modifiziert, damit man 5mm mehr Bauhöhe bekommt. Dazu werden die 2mm und 3mm Distanzplatten durch 2x 5mm Distanzplatten ersetzt. Und der unter starke 5x30x50mm Winkel wird durch einen 5x35x35mm Winkel ersetzt. Es hat sich beim Betrieb mit den dünneren Distanzplatten bei mir eine Anfälligkeit gegen Verschmutzung gezeigt. Mal sehen, ob die 5mm hier auch Abhilfe schaffen. Die alten Waagen waren auch oft mit "überarbeiteten Alu Winkeln" gebaut, weil ich immer mal wieder was geändert oder falsch gemacht habe. Die neuen sind da klarer und bieten daher auch weniger Lücken für Schmutz. Im Herbst wird man sehen, ob sich das gelohnt hat.

Wenn man im Frühling die Waage als Indikator für Pollensuchende Bienen einsetzen möchte, dann ist die Temperaturabhängigkeit relevant. Man hat da zwischen kalten Nächten und sonnigen Tagen schnell 20-30°C Unterschied. Daher benutze ich nun 2x50kg anstatt 2x100kg Sensoren, da ist die Temperaturdrift ebenfalls nur halb so groß.

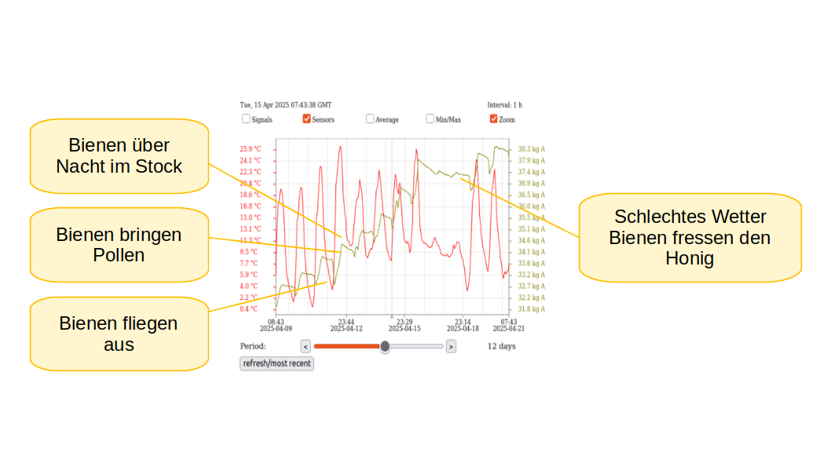
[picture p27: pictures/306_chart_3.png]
Chart im Web-Browser
  

Der Aufbau mit 2 Plattform Wägezellen gibt der Waage ein besondere Stabilität und Unempfindlichkeit beim Aufsetzen von Lasten. Wichtig ist, dass die Wägezellen sehr schlüssig und stabil mit den starken Aluwinkeln (5mm) verschraubt werden, sonst bekommt man anstatt einer Waage eine Wippe. Die obere Platte wird mit kleineren Aluwinkeln (3mm) gegen verrutschen gesichert. Hier muss man darauf achten, dass diese kleineren Aluwinkel (3mm) nur an den oberen starken Aluwinkeln (5mm) anstoßt. Wenn diese auch am unteren starken Aluwinkeln (5mm) anstossen, verfälscht die Reibung das gemessene Gewicht. Daher sind die oberen zwei starken Aluwinkel (5mm) 40,8cm lang und die unteren zwei mit 39,8cm 1cm kürzer. Die kleineren Aluwinkel (3mm) für die untere Platte schließen den Kasten ab. Diese sind um 16mm kürzer als die oberen kleineren Aluwinkel (3mm).

Für die Schraubenköpfe der M6 Schrauben, die die starken Aluwinkel (5mm) mit der Wägezelle verbinden, muss man in die Platten jeweils Aussparungen bohren (siehe oben, mittleres und rechtes Bild). Die unteren starken Aluwinkeln (5mm) verschraube ich ebenfalls mit den 6mm Schrauben und einer Einschlagmutter mit dem unteren Brett.

Zwischen die starken Aluwinkeln (5mm) und den Plattform Wägezellen werden noch Distanzplatten benötigt, damit die Wägezelle auslenken kann.

[cols="1*"]
|===
a|.Anordung der Winkel, Distanzplatten und Wägezelle (Alu) 
Anordnung
|===

Die Anordnung der starken Aluwinkel (5mm), der Wägezelle und der Distanzplatten dazwischen habe ich so gewählt, dass der "Aufsetzschutz" (Überlastungsschutz für die Wägezelle), durch die starken Aluwinkel (5mm) selbst gegeben ist. Wichtig sind dabei das Zusammenspiel der Abmessungen. Meine Wägezelle hat eine Höhe von 22mm. Es werden dann oben und unten Distanzplatten benötigt, damit der Sensor auslenken kann. Hier benutze ich jeweils 5mm. Das ergibt dann eine Höhe von 32mm insgesamt. Meine Aluwinkel haben eine Innenhöhe von 30mm. Somit is die Auslenkung auf 2mm begrenzt.

Vielleicht findet der eine oder andere die Anordnung der Winkel seltsam. Ich erreiche damit zum einen nach außen (links) eine möglichst geschlossen Form zu bilden und zum anderen nach innen (rechts) offen zu sein für das Kabel, das aus der Wägezelle kommt und mit der ADC-Platine verbunden werden muss.

Beim Zusammenschrauben muss man auf die richtige Reihenfolge achten, sonst verdeckt ein Aluwinkel die nächste Schraube. Man beginnt mit den unteren starken Aluwinkel (5mm), den 5mm Distanzplatten und den Plattform Wägezellen. Dann setzt man die zusammengeschraubte Kombination auf das untere Brett und schraubt diese ebenfalls fest. Danach setzt man den oberen starken Aluwinkel (5mm) auf und schraubt diese ebenfalls fest. Ist man damit fertig, dann kann man die kleineren Aluwinkeln (3mm) seitlich, oben und unten montieren. Ich nehme da Spanplattenschrauben 3,5x9,5mm.

== Anschlußplan

[cols="2*"]
|===
a|.ADC Verkabelung 
ADC Verkabelung

a|.Sensorkabel 
Sensorkabel
|===

Von der link:./#der-i2c-adc-wandler-mit-eeprom[i2c ADC-Platine] wird nur der link:https://learn.adafruit.com/adafruit-nau7802-24-bit-adc-stemma-qt-qwiic[ADC NAU7802 von Adafruit] benötigt. Als Kalibrierspeicher wird das Thingy:91X selbst benutzt. Das ist nun fest mit der Waage verbunden. Damit ist die Zuordnung auch fest. Auf der Rückseite der NAU7802/Adafruit Platine ist angegeben, wie man die Farben der Leitungen einer Plattform Wägezelle jeweils anschließt. Ich schliese beide Zellen parallel an, d.h. beide roten Leitungen an `E+/Red`, beide schwarzen an `E-/Black`, beide weißen an `A-/White` und beide grünen an `A+/Green`. Das erfordert etwas geschick. "Gelb" ist die Schirmleitung. Da kann man viel dazu im Web lesen. Wenn es passt, klemme ich die mit auf `E-/Black`. Ansonsten "isolieren" und schauen, ob es funktioniert.    

Die Thingy:91X Sendebox schaltet die Stromversorgung für die ADC-Platinen im Unterschied zu der 2 Kanal-Sendbox ab. Aktiviert werden die Sensoren dann über den internen Spannungsregler des NAU7802. Dieser liefert gemäß dem Datenblatt maximal 10mA. Für zwei Balkensensoren ist das leider zu wenig. Die brauchen je 6-8mA zusammen also mehr als 10mA. Aktuell betreibe ich solche Waagen außerhalb der Spezifikation des NAU7802. Bis jetzt funktioniert es.
 
== Bohrpläne

Die Lage der Bohrungen bei den starken Winkeln ergibt sich, wenn der ein Winkelschenkel liegt und der andere noch ober zeigt. 

[cols="1*"]
|===
a|.oberer starker Winkel, 2x 6mm Bohrungen
Bohrplan starker Winkel Oben

a|.unterer starker Winkel, 4x 6mm Bohrungen
Bohrplan starker Winkel Unten

a|.oberer Winkel, 3x 3,5mm Bohrungen
Bohrplan Winkel

a|.unterer Winkel, 3x 3,5mm Bohrungen (und 1x 11mm)
Bohrplan Aluwinkel

a|.Distanzplatten, 2x 6mm Bohrunge
Bohrplan Distanzplatten

a|.Bretter
Bohrplan Bretter
|===

== Bauteilliste

[cols="3*"]
|===
|Bauteil|Bezugsquelle|Preis (Frühjahr 2025)

|Thingy:91X, Nordic, LTE-M/NB-IoT nRF9151 modem  
a|link:https://www.digikey.de/en/products/detail/nordic-semiconductor-asa/THINGY91X/25650019[Thingy:91X, digikey.de]
|112,77 Euro

|Adafruit NAU7802 24-BIT ADC, I2C
a|link:https://www.digikey.de/en/products/detail/adafruit-industries-llc/4538/16584123[Adafruit NAU7802, digikey.de]
|6,78 Euro

|Adafruit Qwiic Kabel  
a|link:https://www.digikey.de/en/products/detail/adafruit-industries-llc/4210/10230021[Adafruit Qwiic Kabel, digikey.de]
|1,08 Euro

|Gehäuse 115x85x35mm  
a|link:https://www.amazon.de/dp/B0747RGBFF?ref=ppx_yo2ov_dt_b_fed_asin_title[Gehäuse 115x85x35mm, amazon.de]
|8,99 Euro

|Aluwinkel 25x50x5mm, 2x40,8cm (oben)
a|link:https://www.aluminium-online-shop.de/produkt-kategorie/aluminium-profile/winkel[z.B. Aluminium-Online-Shop]
|11,16 Euro (zzgl. Versand ca. 14 Euro je Bestellung)

|Aluwinkel 35x35x5mm, 2x39,8cm (unten)
a|link:https://www.aluminium-online-shop.de/produkt-kategorie/aluminium-profile/winkel[z.B. Aluminium-Online-Shop]
|10,78 Euro (zzgl. Versand)

|Aluwinkel 20x20x3mm, 2x50cm (oben)
a|link:https://www.aluminium-online-shop.de/produkt-kategorie/aluminium-profile/winkel[z.B. Aluminium-Online-Shop]
|5,07 Euro (zzgl. Versand)

|Aluwinkel 25x25x3mm, 2x48,4cm (unten)
a|link:https://www.aluminium-online-shop.de/produkt-kategorie/aluminium-profile/winkel[z.B. Aluminium-Online-Shop]
|6,14 Euro (zzgl. Versand)

|Aluflachstange 30x5mm, für 4 Distanzplatten a 30mm Länge
a|link:https://www.aluminium-online-shop.de/produkt-kategorie/aluminium-profile/winkel[z.B. Aluminium-Online-Shop]
|2,62 Euro (zzgl. Versand)

|Zylinderschrauben A4-80, M6 20mm, 12 Stück
a|link:https://www.schraubenhandel24.de/schrauben/gewindeschrauben/zylinderschrauben/din-912/din-912-zylinderschrauben-isk-edelstahl-a4-80/din-912-zylinderschrauben-edelsta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[z.B. Schraubenhandel24.de]
|22,61 Euro (200 St, zzgl. Versand)

|Federringe A4, M6, 12 Stück
a|link:https://www.schraubenhandel24.de/scheiben/federringe/din-7980/din-7980-federringe-edelstahl-a4/ca-din-7980-a-4-federringe-fuer-zylinderschrauben-6-100st[z.B. Schraubenhandel24.de]
|5,68 Euro (100 St, zzgl. Versand)

|Einschlagmuttern A2, M6 9mm, 4 Stück
a|link:https://www.schraubenluchs.de/Einschlagmuttern-Edelstahl-A2[z.B. Schraubenluchs]
|1,08 Euro (zzgl. Versand)

|Spanplattenschrauben A4, 3,5x9, 5mm, 12 Stück
|Baumarkt
|7 Euro (50 St)

|Plattform Wägezelle E120A 2x 50kg
a|link:https://www.vechta-waagen.com/shop/produkt/single-point-waegezelle-e120a/[Wägezelle, Vechta-Waagen, Temperaturkompenstation]
|24,00 Euro (2x, zzgl. Versand)

|Plattform Wägezelle CZL601 2x 50kg (alternativ)
a|link:https://www.tinkerforge.com/de/shop/load-cell-50kg-czl601.html[Wägezelle, Tinkerforge, Temperaturkompenstation]
|12,99 Euro (2x, zzgl. Versand)

|Siebdruckplatten 45x55cm
|Baumarkt
|17 Euro (2x)

3+a|

'''

|Gesamtsumme
|
a|*260 Euro*
|===

(Anmerkung: leider gibt es einige Artikel nur in größeren Packungen und manches nur mit deutlichen Versandkosten. 260 Euro passen nicht, wenn man die Waage einzeln baut.) 

== Bauteilliste Solarlader

[cols="3*"]
|===
|Bauteil|Bezugsquelle|Preis (Frühjahr 2025)

|Adafruit BQ25185 Solar charger
a|link:https://www.digikey.de/en/products/detail/adafruit-industries-llc/6091/25805553[Adafruit BQ25185, digikey.de]
|6,41 Euro

|Li-Ion Akku ICR18650 3.7V 2200mAh mit JST-PHR-2
a|link:https://eckstein-shop.de/PKNERGY-Lithium-Ion-Battery-ICR-18650-37V-2200mAh-LiPo-Li-Ion-with-JST-PH-Connector[eckstein-shop.de]
|9,48 Euro

|Hohlstecker Buchse
a|link:https://www.amazon.de/dp/B0CMK6XML6[Amazon, 10er Pack]
|6,99 Euro

|Micro JST 1.0 SH 3Pin Stecker
a|link:https://www.amazon.de/dp/B0BNCG27CX[Amazon, 5er Pack]
|6,98 Euro

|Stiftleiste 2pol. abgewinkelt
a|link:https://www.reichelt.de/de/de/shop/produkt/jst_-_stiftleiste_90_1x2-polig_-_xh-185079[Platinenstecker, reichelt.de]
|0,23

|Buchsengehäuse 2pol.
a|link:https://www.reichelt.de/de/de/shop/produkt/jst_-_buchsengehaeuse_1x2-polig_-_xh-185085[Buchse, reichelt.de]
|0,06

|JST Kontakte für Buchse
a|link:https://www.reichelt.de/de/de/shop/produkt/jst_-_crimpkontakt_buchse_-_xh-185091[Platinenstecker, reichelt.de]
|0,10 (2x)

|Solarpanel (abgesetzt), 6V 1.2W
a|link:https://www.amazon.de/ZONADAH-Hangable-Ladeger%C3%A4t-Projekte-Ladewerkzeuge/dp/B09CM1RJHY[(abgesetzt), amazon.de]
|6,99 Euro

3+a|

'''

|Gesamtsumme
|
a|*25 Euro*
|===

== Bauteilliste, Winkel in V2A Edelstahl

[cols="3*"]
|===
|Bauteil|Bezugsquelle|Preis (Frühjahr 2025)

|Edelstahlwinkel 25x50x4mm, 2x40,8cm (oben, alternativ)
a|link:https://www.stahl-shop24.de/edelstahl/edelstahl-winkel/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[z.B. Stahl-Shop 24]
|37,93 Euro (zzgl. Versand 8,20 Euro je Bestellung)

|Edelstahlwinkel 35x35x4mm, 2x39,8cm (unten, alternativ)
a|link:https://www.stahl-shop24.de/edelstahl/edelstahl-winkel/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[z.B. Stahl-Shop 24]
|17,32 Euro (zzgl. Versand)

|Edelstahlwinkel 20x20x3mm, 2x50cm (oben, alternativ)
a|link:https://www.stahl-shop24.de/edelstahl/edelstahl-winkel/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[z.B. Stahl-Shop 24]
|7,42 (zzgl. Versand)

|Edelstahlwinkel 25x25x3mm, 2x48,4cm (unten, alternativ)
a|link:https://www.stahl-shop24.de/edelstahl/edelstahl-winkel/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[z.B. Stahl-Shop 24]
|9,90 (zzgl. Versand)

|Aluflachstange 30x5mm, für 2 Distanzplatten a 30mm Länge
a|link:https://www.aluminium-online-shop.de/produkt-kategorie/aluminium-profile/winkel[z.B. Aluminium-Online-Shop]
|2,62 Euro (zzgl. Versand)

|Aluflachstange 30x6mm, für 2 Distanzplatten a 30mm Länge
a|link:https://www.aluminium-online-shop.de/produkt-kategorie/aluminium-profile/winkel[z.B. Aluminium-Online-Shop]
|2,62 Euro (zzgl. Versand)

3+a|

'''

|Aufpreis
|
a|*40 Euro*
|===

[cols="1*"]
|===
a|.Anordung der Winkel, Distanzplatten und Wägezelle (Edelstahl)
Anordnung
|===

Die starken Edelstahlwinkel sind mit 4mm 1mm dünner, daher muss eine der Distanzplatten 1mm mehr habe und hat so 6mm. 
Edelstahl ist sehr viel stabiler, besonders wenn man 4mm Winkel sägen möchte, kommt man schnell an die Grenzen. Im Gegensatz zu Aluminium ist fertig abglänger Edelstahl nochmal teurer.

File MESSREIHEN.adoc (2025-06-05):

// Mobile-Bienenstock-Waage, Version 2.0, März 2024

:imagesdir: pictures

= Mobile-Bienenstock-Waage, Messreihen
Achim Kraus <achim.kraus@cloudcoap.net>
v0.1, 2023-12-05

Waagen bauen stellt sich dann doch als nicht so einfach raus. Viele Komponenten sind für andere Anwendungen gedacht. Normale Waage, z.B. Personen-Waagen werden meist nur für eine kurzen Zeitraum belastet. Und meist bei sehr ähnlichen Temperaturen. Eine Bienenstockwaage wird aber über lange Zeit belastet und im Freien sind die Temperaturschwankungen erheblich.
  
## Wägezellen
  
Der erste Faktor, die Abweichung bei Dauerbelastung, wird `Creep` genannt. Die Temperaturanweichung wird in eine 0-Punktverschieben und eine Faktorveränderung angegeben.

[cols="4*"]
|===
|Wägezelle|Creep|Temp. 0-Punkt|Temp. Faktor

||%F.S/30min|%F.S/10°C|%F.S/10°C

|CK-50-Y4 4x50kg|0,05|0,05|0,05

|CZL601 100kg|0,019|0,019|0,016

|Vechta E120A 100kg|0,015|0,017|0,016

|Vechta E30A 200kg|0,016|0,018|0,018

|Mavin NA1 50kg|0,02|0,03|0,02
|===

`%F.S` steht dabei für "Full-Scale" also Vollausschlag. z.B. bei 100kg und 0,05% ergibt das 50g.

Gemäß dem Datenblättern sind die Plattform Wägezelle besser und geeignet und liegen dicht beieinander. Die Plattform Wägezelle haben meistens bereits eine Temperatur-Kompensation und sind deshalb deutlich weniger Empfindlich gegenüber Temperaturschwankungen.

Das spiegelt letztlich den Anwendungsfall und die Kostenoptimierung wieder. Wenn eine Personenwaage kurz vor dem Wiegen auf 0 gestellt wird, dann fallen Creep und die 0-Punktverschiebeung nicht ins "Gewicht". Bei einer Bienenstockwaage bedeutet dies dann, dass man das Gewicht mit dem des Vortages bei in etwas selber Temperatur vergleichen kann und so eine Entwicklung ablesen kann. Für mehr braucht es dann eben die besser geeigneten Plattformsensoren.

Wenn man die Sensoren auswählt, muss man sich auch zwischen der maximal zulässigen Last und der Temperaturabweichung entscheiden, 50kg Sensor hat nur die halbe Temperaturabweichung als die 100kg Variante. 

Außer diesen Faktoren spielt auch noch die Erregerspannung eine Rolle. Die Ausgangsspannung, mit der man dann das Gewicht bestimmen kann, hängt eben von dieser Erregerspannung ab. Deshalb ist es gannz wichtig, dass diese Erregerspannung auch die Referenzspannung des ADC ist, sonst bekommt man hier schnell Fehler. Bleibt, dass man mit einer höheren Erregerspannung im Allgemeinen eine höhere Auflösung bekommen würde. Aber für eine Waage die mit Batterien betrieben wird, muss man da Kompromisse eingehen. 

Meine `Mobile-Bienenstock-Waage` benutzt eine Systemspannung von 3,3V. Als analoge Erregerspannung leite ich davon 2,7V ab, indem ich den ADC (NAU7802) entsprechend konfiguriere.

## ADC

Auch die Präzision des ADC hängt von einigen Faktoren ab. Die gängigen ADC für Waagen bieten meist eine Auflösung von bis zu 24 Bit an. Wenn man aber die Referenzspannung und den gewählten Verstärkungsfaktor hinzunimmt, dann geht diese Auflösung rasch runter. Bei dem benutzten NAU7802 kann man das der Tabelle 1.5.2 auf Seite 10 des Datenblatt entnehmen. Bei 3,3V und Verstärkungsfaktor (gain) 64 bleiben 17 Bit.

Der NAU7802 weißt eine geringe Temperaturabhängigkeit auf, die im Verhältnis zu der der Sensoren in der Praxis aber vernachlässigbar erscheint. Was man aber vor jeder Messung machen sollte ist den 0-Punkt kalibirieren. Dazu hat der NAU7802 eine interne Kalibrierungsfunktion und alternativ die Möglichkeit, die Analogeingänge intern zu verbinden. Ich nutze den 2. Ansatz, da man da selber filtern kann, wann die Werte stabil genung sind. 

## Messreihen

Zu Begin hatte ich den Plan, hier diverse Messreichen aufzuführen. Aber zumindest bei meinen Tests stellte sich raus, dass man sich da ganz schön einfach selber täuschen kann. Siehe meine Beiträge in link:https://community.hiveeyes.org/t/diskussion-zum-nuvoton-nau7802-24bit-2ch-adc/3237/25[Hiveeyes - Diskussion zum Nuvoton NAU7802 24bit 2ch ADC].

Es gibt auch Messreihen von anderen, z.B. link:https://community.hiveeyes.org/t/strain-gauge-load-cell-tests-in-a-diy-climate-chamber/1642/20[Hiveeyes,Strain gauge load cell tests in a DIY climate chamber] oder link:https://beelogger.de/sensoren/waegezellen_hx711/stockwaage-temperaturkompensation/[beelogger - Temperaturkompensation].

Beides spiegelt meine Erfahrungen mit systematischeren Messungen diese Frühjahr (2025) wieder. Bei manchen Sensoren sieht man einen linearen Zusammenhang mit der Temperatur, und eine verbesserte Kompensation ist dann möglich. Bei anderen Sensoren ist das nicht linear. Bis jetzt scheint es für mich auch so zu sein, dass die Varianz zwischen den Sensoren eines Herstellers groß ist, und ich keinen Hersteller gefunden habe, der da eine geringere Varianz oder generell eine geringere Tempeaturabweichung hat.

Messungen mit 8 facher Verstärkung:
 
[cols="3*"]
|===
a|.100kg (Widerstände)
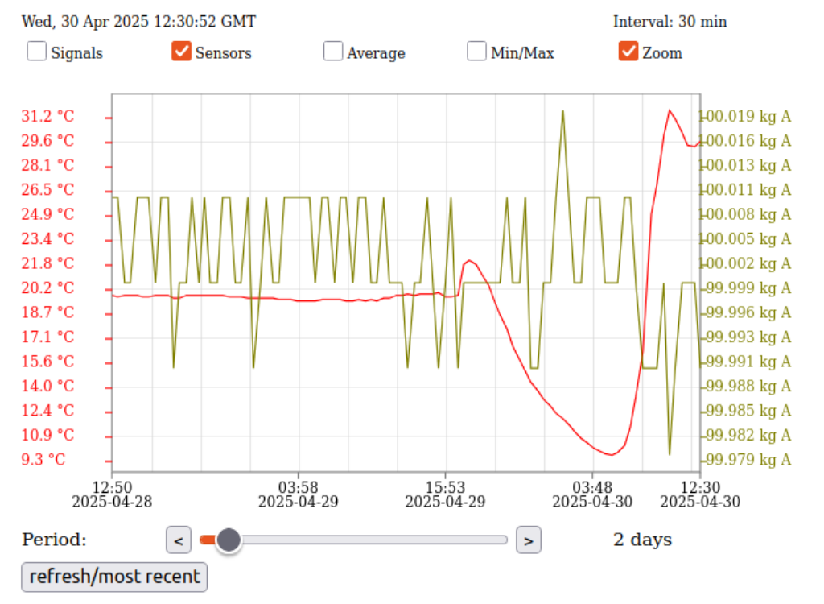
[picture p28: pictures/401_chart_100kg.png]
100kg (Widerstände)
 
a|.0kg (2x50kg Wägezellen)
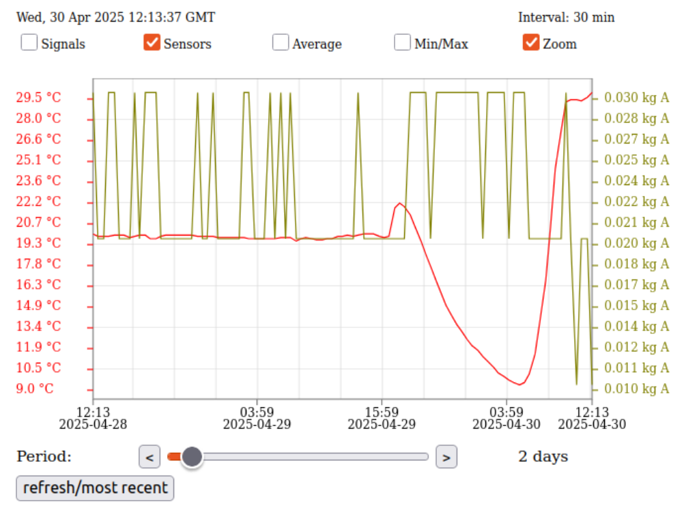
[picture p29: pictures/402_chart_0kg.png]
0kg (2x50kg Wägezellen)

a|.10kg (2x50kg Wägezellen)
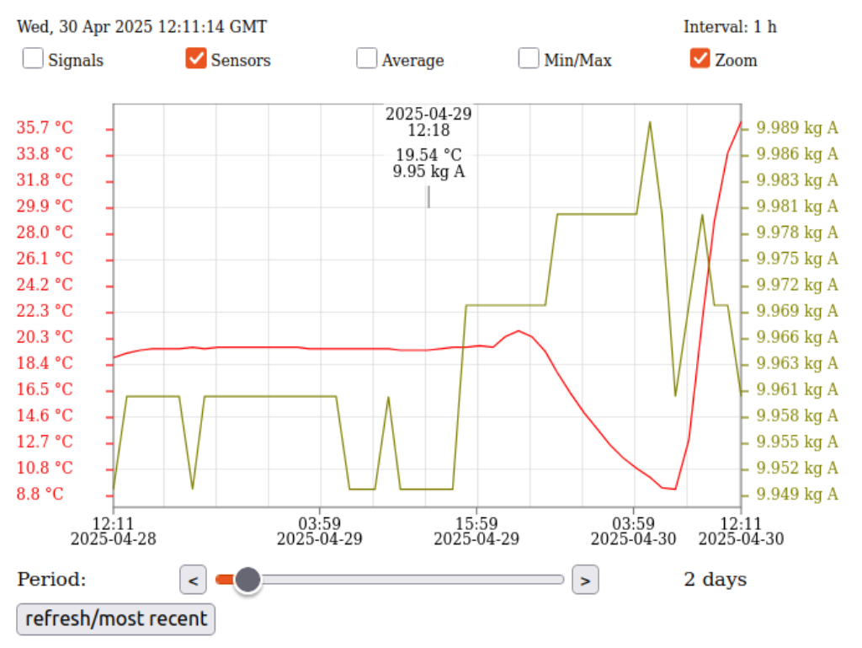
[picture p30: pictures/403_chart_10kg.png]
10kg (2x50kg Wägezellen)

|===

Messungen mit 32 facher Verstärkung, unterschiedliche Sensoren:
 
[cols="3*"]
|===
a|.2x50kg Wägezellen
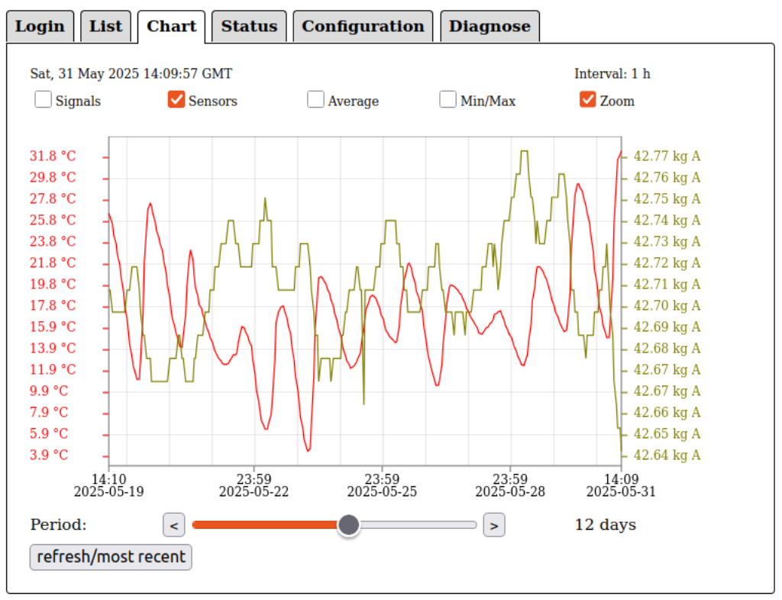
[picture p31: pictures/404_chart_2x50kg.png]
2x50kg Wägezellen
 
a|.2x100 kg Wägezellen
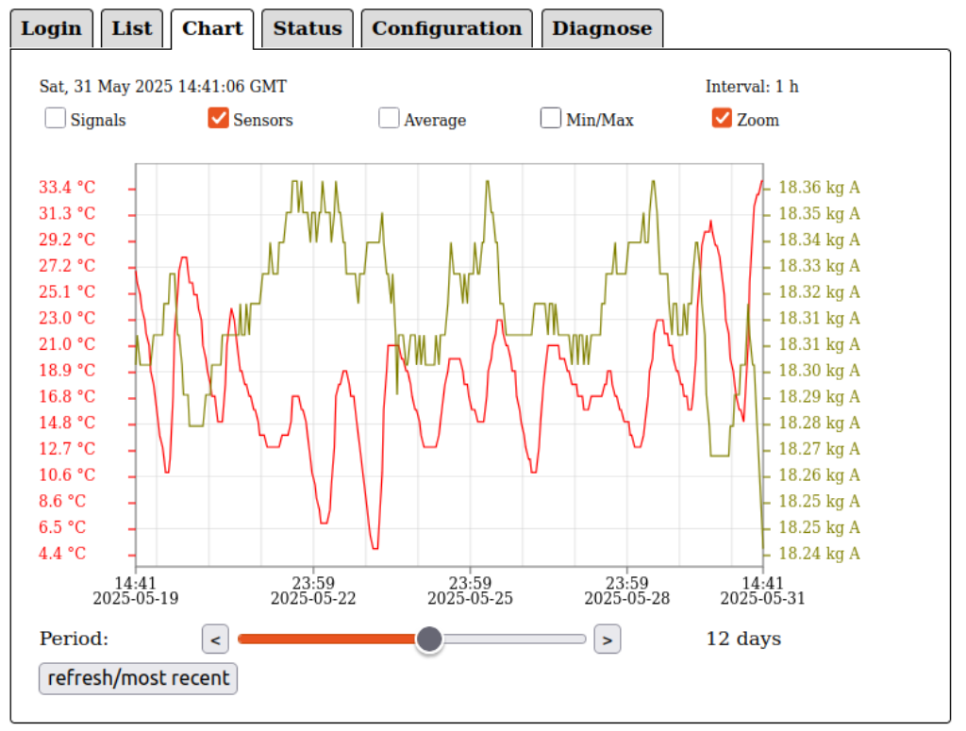
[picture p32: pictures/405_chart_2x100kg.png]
2x100kg Wägezellen

a|.2x100 kg Wägezellen (anderer Hersteller)
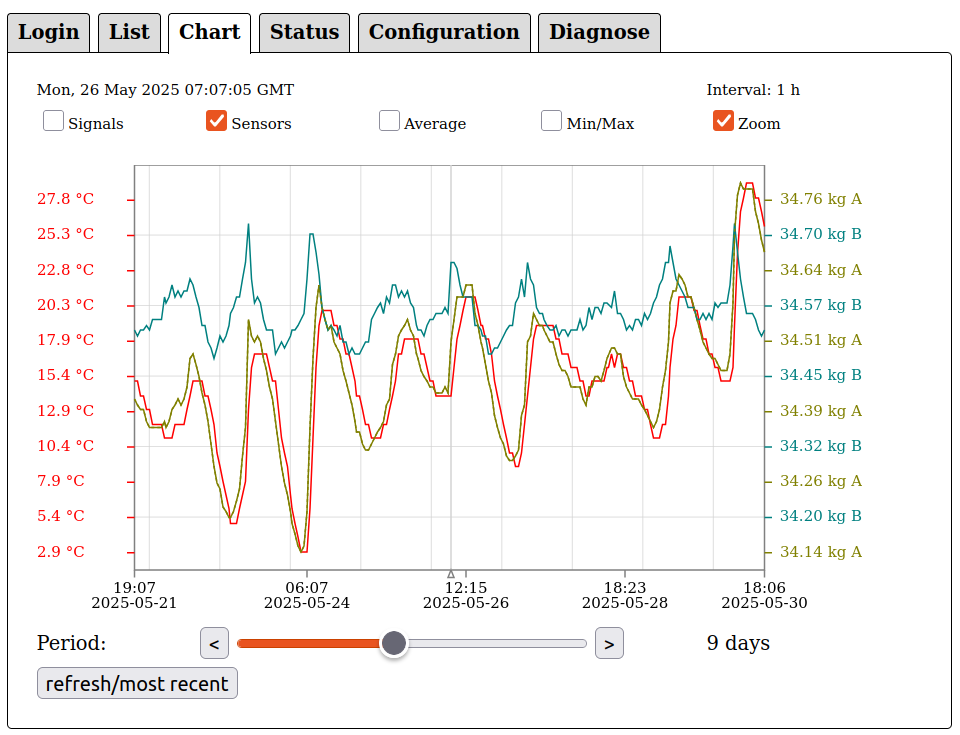
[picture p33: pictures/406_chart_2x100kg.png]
2x100kg Wägezellen)

|===

## Mein Fazit:

2x50kg lieferte bei meinen Test die geringste Temperaturabweichung, die Unterschiede zwischen den Wägezellen (CZL601, Vechta E120A, Mavin NA1) sind gering.
 
Die 2x100kg haben ein höhere Abweichung und bei meinen Tests gab es da dann sehr deutlich "Ausreißer" bei den Wägezellen (CZL601, Vechta E120A). Das Diagramm ganz rechts zeigt zusätzlich mit der "kg B" Kurve an, was eine temperatur-abhängige Kompensation bringen kann. Einschränkend muss erwähnt werden, dass die Temperatur nicht die vom Sensor sondern von der Sendebox ist. Die Kompensationsdaten (Gewichtsabweichung pro °C) muss für jede Waage ermittelt werden.    

Abweichungen bei 30° Temperaturdifferenz:

[cols="3*"]
|===
|Wägezelle|Last <20kg|Last >40kg

|2x50kg|70g|130g

|2x100kg|120g|-

|2x100kg|740g|-

|2x100kg (komp.)|240g|-
|===

Daher erscheint mir die Wahl mit 2x50kg die Beste zu sein.

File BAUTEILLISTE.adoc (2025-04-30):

// Mobile-Bienenstock-Waage, Version 2.0, Mai 2024

:imagesdir: pictures

= Mobile-Bienenstock-Waage, Bauteilliste, Herbst 2024
Achim Kraus <achim.kraus@cloudcoap.net>
v0.4, 2024-10-04

== Bauteilliste, Waage 

[cols="3*"]
|===
|Bauteil|Bezugsquelle|Preis (Herbst 2024)

|Adafruit NAU7802 24-BIT ADC, I2C
a|link:https://www.digikey.de/en/products/detail/adafruit-industries-llc/4538/16584123[Adafruit NAU7802, digikey.de]
|6,78 Euro

|AT24HC04B-PU EEPROM, I2C
a|link:https://www.digikey.de/en/products/detail/microchip-technology/AT24HC04B-PU/1886137[AT24HC04B, digikey.de]
|0,62 Euro

|Folien-Kondensator, 100nF
a|link:https://www.reichelt.de/mks2-pet-kondensator-100-nf-10-63-vdc-rm-5-mks2-63-100n-p12349.html[Folien-Kondensator, reichelt.de]
|0,29 Euro

|Gehäuse, ca 50x50x15mm
a|link:https://www.digikey.de/de/products/detail/bud-industries/CU-18421-B/5291576[Gehäuse, digikey.de]
|3,17 Euro

|Kabel, 2m, 12mm Buchse - offenes Ende
a|link:https://www.reichelt.de/sensorleitung-m12-4-pol-ku-offenes-ende-2-m-lut-1200-004-2-p222963.html[Kabel, reichelt.de]
|8,85 Euro

|Siebdruckplatten 45x55cm
|Baumarkt
|17 Euro (2x)

|Personenwaage Wägezelle 4x 50kg (einfache Waagenausführung)
a|link:https://www.amazon.de/dp/B07HBP1167[Wägezelle, amazon.de]
|10,99 Euro (für 10 Stück, es werden nur 4 benötigt.)

3+a|

'''

|Gesamtsumme je Waage
|Einfache Ausführung
a|*60 Euro*
|===

Der mechanische Aufbau unterscheidet sich je nach Waagentype stark. 

Für den Aufbau mit den einfachen Personenwaagen Sensoren kann man sich Sensorhalter mit einem 3D-Drucker und link:halterung_fuer_waegezellen.stl[Halterung für Wägezellen] erstellen. Der Halter passt für die Sensoren in der Bestellliste und auch für link:https://www.kern-sohn.com/shop/de/produkte/messinstrumente/CK-50-Y4/[Kern CK 50-Y4]. Die Sensoren werden durch den Abstandshalter etwas von der Siebdruckplatten weg gehalten, was die Erwärmung durch Sonne über diese Platten verringert. Die Seite des Abstandshalters mit der Lücke ist für das Kabel vom `Kern CK 50-Y4` Sensor.

== Bauteilliste, Waage mit Plattform Wägezellen 

[cols="3*"]
|===
|Bauteil|Bezugsquelle|Preis (Herbst 2023)

|Gehäuse, ca 80x40x20mm (alternativ)
a|link:https://www.digikey.de/de/products/detail/hammond-manufacturing/1551KFLBK/2094805[Gehäuse, digikey.de]
|3,40 Euro

|Aluwinkel 50x30x5mm, 2x40,0cm (unten)
a|link:https://www.aluminium-online-shop.de/produkt-kategorie/aluminium-profile/winkel[z.B. Aluminium-Online-Shop]
|12,35 Euro (zzgl. Versand ca. 14 Euro je Bestellung)

|Aluwinkel 25x50x5mm, 2x41cm (oben)
a|link:https://www.aluminium-online-shop.de/produkt-kategorie/aluminium-profile/winkel[z.B. Aluminium-Online-Shop]
|12,14 Euro (zzgl. Versand)

|Aluwinkel 20x20x3mm, 2x51cm
a|link:https://www.aluminium-online-shop.de/produkt-kategorie/aluminium-profile/winkel[z.B. Aluminium-Online-Shop]
|5,55 Euro (zzgl. Versand)

|Aluwinkel 20x20x3mm, 2x49,6cm
a|link:https://www.aluminium-online-shop.de/produkt-kategorie/aluminium-profile/winkel[z.B. Aluminium-Online-Shop]
|5,40 Euro (zzgl. Versand)

|Zylinderschrauben A4-80, M6 20mm, 12 Stück
a|link:https://www.schraubenhandel24.de/schrauben/gewindeschrauben/zylinderschrauben/din-912/din-912-zylinderschrauben-isk-edelstahl-a4-80/din-912-zylinderschrauben-edelsta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[z.B. Schraubenhandel24.de]
|22,61 Euro (200 St, zzgl. Versand)

|Federringe A4, M6, 12 Stück
a|link:https://www.schraubenhandel24.de/scheiben/federringe/din-7980/din-7980-federringe-edelstahl-a4/ca-din-7980-a-4-federringe-fuer-zylinderschrauben-6-100st[z.B. Schraubenhandel24.de]
|5,68 Euro (100 St, zzgl. Versand)

|Einschlagmuttern A2, M6 9mm, 4 Stück
a|link:https://www.schraubenluchs.de/Einschlagmuttern-Edelstahl-A2[z.B. Schraubenluchs]
|1,08 Euro (zzgl. Versand)

|Spanplattenschrauben A4, 3,5x9, 5mm, 12 Stück
|Baumarkt
|7 Euro (50 St)

|Plattform Wägezelle CZL601 2x 100kg (alternativ)
a|link:https://www.tinkerforge.com/de/shop/load-cell-100kg-czl601.html[Wägezelle, Tinkerforge, Temperaturkompenstation]
|14,00 Euro (2x)

|Plattform Wägezelle E120A 2x 100kg (alternativ)
a|link:https://www.vechta-waagen.com/shop/produkt/single-point-waegezelle-e120a/[Wägezelle, Vechta-Waagen, Temperaturkompenstation]
|24,00 Euro (2x)

|Plattform Wägezelle H40A 150kg (alternativ)
a|link:https://www.bosche.eu/waagenkomponenten/waegezellen/plattform-waegezellen/plattform-waegezellen-h40a[Wägezelle, Bosche, Test steht aus]
|67,00 Euro

3+a|

'''

|Mehrpreis je Waage
|Plattform Wägezellen Ausführung
a|*80 Euro*
|===

Für den Aufbau mit 2 Plattform Wägezelle, z.B. link:https://www.tinkerforge.com/de/shop/load-cell-100kg-czl601.html[CZL601 100kg], werden Aluwinkel benötigt. Man muss aber auf jeden Fall die maximale Belastung beachten, sonst gehen die Sensoren leicht kaputt (link:https://www.bosche.eu/media/pdf/03/f0/32/Hilfe-bei-der-Auswahl-von-Wa-gezellen-TIPP.pdf[Wägezellen Auswahl]). Der Preis liegt dann, je nach Sensor, pro Waage um 80 Euro und mehr höher.

Mein Fokus liegt auf der Elektronik, daher führe ich weitere Bauarten hier nicht auf. Man findet diese aber leicht im Web.
 
== Bauteilliste, Sendebox

[cols="3*"]
|===
|Bauteil|Bezugsquelle|Preis (Herbst 2023)

1.2+a|nRF9160 Feather
a|link:https://www.circuitdojo.com/products/nrf9160-feather[nRF9160 feather, www.circuitdojo.com]
|99 $ + Importkosten.

a|Alternativ link:https://www.digikey.de/en/products/detail/circuit-dojo/PASSY-NRF9160-FEATHER/13668137[nRF9160 feather, digikey.de]
|105,04 Euro

1.2+a|LTE Antenne
a|link:https://www.circuitdojo.com/products/nrf9160-feather[LTE Antenne, www.circuitdojo.com]
|5$ + Importkosten.

a|Alternativ link:https://www.digikey.de/en/products/detail/unictron-technologies-corporation/H2B4MH1F2F0100/9921462[LTE Antenne, digikey.de]
|4,80 Euro

|Einbaustecker Kunststoff, 50cm, 12mm
a|link:https://www.reichelt.de/einbausteckverbinder-m12-4-pol-stecker-schwarz-lut-1230-04-100-p347094.html[Einbaustecker Kunststoff, reichelt.de]
|4,70 Euro (2x ?)

|Einbaustecker metall, 50cm, 12mm (alternativ)
a|link:https://www.reichelt.de/einbausteckverbinder-m12-4-pol-stecker-0-5-m-lut-1230-t16cw04-p223037.html[Einbaustecker Metall, reichelt.de]
|5,99 Euro (2x ?)

|Schutzkappe für Einbaustecker, 12mm, (falls nur 1 Waage angeschlossen wird)
a|link:https://www.reichelt.de/schutzkappe-m12-stecker-lut-cp0-p223055.html[Schutzkappe, reichelt.de]
|0,60 Euro

|Platinenstecker/Stiftleiste 4pol.
a|link:https://www.reichelt.de/jst-stiftleiste-gerade-1x4-polig-xh-jst-xh4p-st-p185075.html[Platinenstecker, reichelt.de]
|0,23 (2x)

|Platinenstecker/Buchsengehäuse 4pol.
a|link:https://www.reichelt.de/jst-buchsengehaeuse-1x4-polig-xh-jst-xh4p-bu-p185087.html[Buchsengehäuse, reichelt.de]
|0,09 (2x)

|Platinenstecker/Buchse
a|link:https://www.reichelt.de/jst-crimpkontakt-buchse-xh-jst-xh-ckb-p185091.html[Buchse, reichelt.de]
|0,15 (8x)

|Gehäuse, 160x80x55mm
a|link:https://www.reichelt.de/industriegehaeuse-160-x-80-x-55-mm-ip66-lichtgrau-5u320000-p324381.html[Gehäuse, reichelt.de]
|9,20 Euro

|Laborkarte 3-Loch-Lötinseln
a|link:https://www.reichelt.de/laborkarte-cem3-rm-2-54-mm-3-loch-loetinseln-re-310-s1-p105479.html[Laborkarte, reichelt.de]
|6,50 Euro

|Batteriehalter 3xAA mit Deckel
a|link:https://www.reichelt.de/batteriehalter-fuer-3-mignon-aa-geschlossen-halter-3xaa-p44631.html[Batteriehalter, reichelt.de]
|1,35 Euro

|Pfostenstecker, 10 pol.
a|link:https://www.reichelt.de/wannenstecker-10-polig-gerade-wsl-10g-p22816.html[Pfostenstecker, reichelt.de]
|0,13 Euro

|Pfostenbuchse, 10 pol.
a|link:https://www.reichelt.de/pfostenbuchse-10-polig-mit-zugentlastung-pfl-10-p14571.html[Pfostenbuchse, reichelt.de]
|0,10 Euro

|Flachbandkabel, 10 pol.
a|link:https://www.reichelt.de/flachbandkabel-awg28-10-pol-grau-3m-ring-awg-28-10g-3m-p47637.html[Flachbandkabel 3m, reichelt.de]
|3,59 Euro (es werden nur 15cm benutzt)

|Taster
a|link:https://www.voelkner.de/products/73350/TRU-Components-701802-GQ16F-10-J-N-Vandalismusgeschuetzter-Drucktaster-48-V-DC-2A-1-x-Aus-Ein-tastend-IP65-1St..html[Taster, voelkner.de]
|4,99 Euro

|RGB LED
a|link:https://www.voelkner.de/products/1028434/HuiYuan-5039R2G3B2C-ESB-LED-bedrahtet-Rot-Gruen-Blau-Rund-5mm-1900-mcd-2350-mcd-1850-mcd-45-20mA.html[RGB LED, voelkner.de]
|0,75 Euro

|LED Fassung
a|link:https://www.voelkner.de/products/29240/Signal-Construct-SML1089-SML1089-LED-Fassung-Metall-Passend-fuer-LEDs-LED-5mm-Schraubbefestigung.html[LED Fassung, voelkner.de]
|4,49 Euro

|Akkus und Ladegerät, NiMh 2000mAh
a|link:https://www.amazon.de/Panasonic-eneloop-LED-Anzeigen-Sicherheitsfunktionen-Mignon-Akkus-blue/dp/B0B5X4PKW1[Akkus, amazon.de]
|31,99 Euro (es werden nur 3 Stück benutzt)

|SIM-Karte für LTE-M und NB-IoT
|Viele Quellen mit unterschiedlichen Leistungen
|10-30 Euro (reichen 3-10 Jahre)

3+a|

'''

|Gesamtsumme
|
a|*200 Euro*
|===

== Bauteilliste, Thingy:91X + NAU7802

[cols="3*"]
|===
|Bauteil|Bezugsquelle|Preis (Frühjahr 2025)

|Thingy:91X, Nordic, LTE-M/NB-IoT nRF9151 modem  
a|link:https://www.digikey.de/en/products/detail/nordic-semiconductor-asa/THINGY91X/25650019[Thingy:91X, digikey.de]
|112,77 Euro

|Adafruit NAU7802 24-BIT ADC, I2C
a|link:https://www.digikey.de/en/products/detail/adafruit-industries-llc/4538/16584123[Adafruit NAU7802, digikey.de]
|6,78 Euro

|Adafruit Qwiic Kabel  
a|link:https://www.digikey.de/en/products/detail/adafruit-industries-llc/4210/10230021[Adafruit Qwiic Kabel, digikey.de]
|1,08 Euro

|Gehäuse 115x85x35mm  
a|link:https://www.amazon.de/dp/B0747RGBFF?ref=ppx_yo2ov_dt_b_fed_asin_title[Gehäuse 115x85x35mm, amazon.de]
|8,99 Euro

|Aluwinkel 35x35x5mm, 2x40,0cm (unten)
a|link:https://www.aluminium-online-shop.de/produkt-kategorie/aluminium-profile/winkel[z.B. Aluminium-Online-Shop]
|10,78 Euro (zzgl. Versand ca. 14 Euro je Bestellung)

|Aluwinkel 25x50x5mm, 2x41cm (oben)
a|link:https://www.aluminium-online-shop.de/produkt-kategorie/aluminium-profile/winkel[z.B. Aluminium-Online-Shop]
|11,16 Euro (zzgl. Versand)

|Aluwinkel 20x20x3mm, 2x51cm
a|link:https://www.aluminium-online-shop.de/produkt-kategorie/aluminium-profile/winkel[z.B. Aluminium-Online-Shop]
|5,07 Euro (zzgl. Versand)

|Aluwinkel 25x25x3mm, 2x49,6cm
a|link:https://www.aluminium-online-shop.de/produkt-kategorie/aluminium-profile/winkel[z.B. Aluminium-Online-Shop]
|6,14 Euro (zzgl. Versand)

|Aluflachstange 30x5mm, 4x30mm (Distanzplatten)
a|link:https://www.aluminium-online-shop.de/produkt-kategorie/aluminium-profile/winkel[z.B. Aluminium-Online-Shop]
|2,62 Euro (zzgl. Versand)

|Zylinderschrauben A4-80, M6 20mm, 12 Stück
a|link:https://www.schraubenhandel24.de/schrauben/gewindeschrauben/zylinderschrauben/din-912/din-912-zylinderschrauben-isk-edelstahl-a4-80/din-912-zylinderschrauben-edelsta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[z.B. Schraubenhandel24.de]
|22,61 Euro (200 St, zzgl. Versand)

|Federringe A4, M6, 12 Stück
a|link:https://www.schraubenhandel24.de/scheiben/federringe/din-7980/din-7980-federringe-edelstahl-a4/ca-din-7980-a-4-federringe-fuer-zylinderschrauben-6-100st[z.B. Schraubenhandel24.de]
|5,68 Euro (100 St, zzgl. Versand)

|Einschlagmuttern A2, M6 9mm, 4 Stück
a|link:https://www.schraubenluchs.de/Einschlagmuttern-Edelstahl-A2[z.B. Schraubenluchs]
|1,08 Euro (zzgl. Versand)

|Spanplattenschrauben A4, 3,5x9, 5mm, 12 Stück
|Baumarkt
|7 Euro (50 St)

|Plattform Wägezelle E120A 2x 100kg
a|link:https://www.vechta-waagen.com/shop/produkt/single-point-waegezelle-e120a/[Wägezelle, Vechta-Waagen, Temperaturkompenstation]
|24,00 Euro (2x)

|Plattform Wägezelle CZL601 2x 100kg (alternativ)
a|link:https://www.tinkerforge.com/de/shop/load-cell-100kg-czl601.html[Wägezelle, Tinkerforge, Temperaturkompenstation]
|14,00 Euro (2x)

|Siebdruckplatten 45x55cm
|Baumarkt
|17 Euro (2x)

3+a|

'''

|Gesamtsumme
|
a|*260 Euro*

|===

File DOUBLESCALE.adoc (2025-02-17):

// Mobile-Bienenstock-Waage, Version 2.0, Mai 2024

:imagesdir: pictures

= Mobile-Bienenstock-Waage
Achim Kraus <achim.kraus@cloudcoap.net>
v0.3, 2024-05-07

== Waagenaufbau mit 2 Plattform Wägezellen

[cols="3*"]
|===
a|.Untere Platte mit Aluwinkel 5mm und Wägezellen
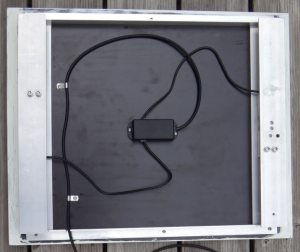
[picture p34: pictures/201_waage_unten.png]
Untere Platte mit Aluwinkel 5mm und Wägezellen montiert
 
a|.Schraubenköpfe
Schraubenkopf Schraubenkopf
.Verschraubung mit unterem Brett
Verschraubung 
a|.Obere Platte mit Bohrungen für Schraubenköpfe
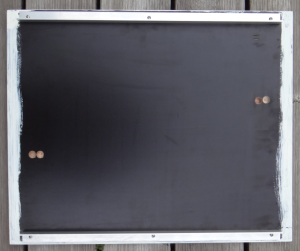
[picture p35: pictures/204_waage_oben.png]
Obere Platte mit Aluwinkel 3mm
 

3+a|.Zwei zusammengebaute Waagen
image::205_waage_mit sendebox.png[Zwei zusammengesetzte Waage, align=center] 

|===

Ein sehr ähnliche Bauform wird oft mit dem Name "Double" bezeichnet. 

Die Waage besteht aus 2 Plattform Wägezellen, die der Waage ein besondere Stabilität und Unempfindlichkeit beim Aufsetzen von Lasten geben. Wichtig ist, dass die Wägezellen sehr schlüssig und stabil mit den starken Aluwinkeln (5mm) verschraubt werden, sonst bekommt man anstatt einer Waage eine Wippe. Die obere Platte wird mit kleineren Aluwinkeln (3mm) gegen verrutschen gesichert. Hier muss man darauf achten, dass diese kleineren Aluwinkel (3mm) nur an den oberen starken Aluwinkeln (5mm) anstoßt. Wenn diese auch am unteren starken Aluwinkeln (5mm) anstossen, verfälscht die Reibung das gemessene Gewicht. Daher sind die oberen zwei starken Aluwinkel (5mm) 41cm lang und die unteren zwei mit 39,6cm etwas kürzer. Die kleineren Aluwinkel (3mm) für die untere Platte schließen den Kasten ab. Diese sind ebenfalls um 14mm kürzer als die oberen kleineren Aluwinkel (3mm).

Für die Schraubenköpfe der M6 Schrauben, die die starken Aluwinkel (5mm) mit der Wägezelle verbinden, muss man in die Platten jeweils Aussparungen bohren (siehe oben, mittleres und rechtes Bild). Die unteren starken Aluwinkeln (5mm) verschraube ich ebenfalls mit den 6mm Schrauben und einer Einschlagmutter mit dem unteren Brett.

Zwischen die starken Aluwinkeln (5mm) und den Plattform Wägezellen werden noch Distanzplatten benötigt, damit die Wägezelle auslenken kann.

[cols="1*"]
|===
a|.Anordung der Winkel, Distanzplatten und Wägezelle 
Anordnung
|===

Die Anordnung der starken Aluwinkel (5mm), der Wägezelle und der Distanzplatten dazwischen habe ich so gewählt, dass der "Aufsetzschutz" (Überlastungsschutz für die Wägezelle), durch die starken Aluwinkel (5mm) selbst gegeben ist. Wichtig sind dabei das Zusammenspiel der Abmessungen. Meine Wägezelle hat eine Höhe von 22mm. Es werden dann oben und unten Distanzplatten benötigt, damit der Sensor auslenken kann. Hier benutze ich oben 3mm und unten 2mmm. Das ergibt dann eine Höhe von 27mm insgesamt. Meine Aluwinkel haben eine Innenhöhe von 25mm. Somit is die Auslenkung auf 2mm begrenzt.

Vielleicht findet der eine oder andere die Anordnung der Winkel seltsam. Ich erreiche damit zum einen nach außen (links) eine möglichst geschlossen Form zu bilden und zum anderen nach innen (rechts) offen zu sein für das Kabel, das aus der Wägezelle kommt und mit der ADC-Platine verbunden werden muss.

Beim Zusammenschrauben muss man auf die richtige Reihenfolge achten, sonst verdeckt ein Aluwinkel die nächste Schraube. Man beginnt mit den unteren starken Aluwinkel (5mm), den 2mm Distanzplatten und den Plattform Wägezellen. Dann setzt man die zusammengeschraubte Kombination auf das untere Brett und schraubt diese ebenfalls fest. Danach setzt man den oberen starken Aluwinkel (5mm) auf und schraubt diese ebenfalls fest. Ist man damit fertig, dann kann man die kleineren Aluwinkeln (3mm) seitlich, oben und unten montieren. Ich nehme da Spanplattenschrauben 3,5x9,5mm.    

== Anschlußplan

[cols="2*"]
|===
a|.ADC Verkabelung 
ADC Verkabelung

a|.Sensorkabel 
Sensorkabel
|===

Wie bei der Beschreibung der link:./#der-i2c-adc-wandler-mit-eeprom[i2c ADC-Platine] schon erwähnt, müssen die Sensoren mit der ADC Platine verbunden werden. Auf der Rückseite der NAU7802/Adafruit Platine ist angegeben, wie man die Farben der Leitungen einer Plattform Wägezelle jeweils anschließt. Ich schliese beide Zellen parallel an, d.h. beide roten Leitungen an `E+/Red`, beide schwarzen an `E-/Black`, beide weißen an `A-/White` und beide grünen an `A+/Green`. Das erfordert etwas geschick. "Gelb" ist die Schirmleitung. Da kann man viel dazu im Web lesen. Wenn es passt, klemme ich die mit auf `E-/Black`. Ansonsten "isolieren" und schauen, ob es funktioniert.    

Die Sendebox schaltet die Stromversorgung für die ADC-Platinen nicht ab. Der Ruhstrom dies ADC-Platinen ist sehr gering. Aktiviert werden die Sensoren dann über den internen Spannungsregler des NAU7802. Dieser liefert gemäß dem Datenblatt maximal 10mA. Für zwei Balkensensoren ist das leider zu wenig. Die brauchen je 6-8mA zusammen also mehr als 10mA. Aktuell betreibe ich solche Waagen außerhalb der Spezifikation des NAU7802. Bis jetzt funktioniert es.

Alternativ braucht man einen externen Spanungsregler mit `ENable` Eingang, z.B. link:https://www.ti.com/lit/ds/symlink/lp2980-n.pdf[LP2980-N]. `E+` muss dann dort mit den `ENable` (On/OFF PIN 3) verbunden werden und `E+` der Sensoren mit dem Ausgang des Spannungsreglers. Man muss auch die Empfehlungen für zusätzlich Kondensatoren beachten, meist 1µF low ESR und 0,1µF Folienkondensator. Und man muss auch auf eine "low drop" Version achten. `Vcc` beträgt nur 3,3V und am Sensor sollte man 2,7-3,0V haben. Leider ist bei der Adafruit Version der Eingang für `REFP` nicht nutzbar, damit geht dann die ratiometrische Beschaltung des ADC-Boards verloren, wenn man den externen Spanungsregler über `E+` schalten möchte. Die ratiometrische Beschaltung sorgt sonst dafür, dass langsame Abweichungen in der analogen Spannung das Messergebnis nicht beeinflußen.
 
== Bohrpläne

[cols="1*"]
|===
a|.Bohrplan Oben, 6mm Bohrungen
Bohrplan starke Aluwinkel Oben

a|.Bohrplan Unten, 6mm Bohrungen
Bohrplan starke Aluwinkel Unten

a|.Bohrplan Oben, 3,5mm Bohrungen
Bohrplan Aluwinkel

a|.Bohrplan Unten, 3,5mm Bohrungen
Bohrplan Aluwinkel

a|.Bohrplan Bretter
Bohrplan Bretter

|===

== Bauteilliste

Eine Liste mit Vorschlägen für die verwendeten Bauteilen und deren Bezugsquellen habe ich auch erstellt.
Es gibt bei den einzelnen Bauteilen Alternativen und alternative Bezugsquellen.

ifdef::env-github[]
link:BAUTEILLISTE.adoc[Bauteilliste]
endif::[]

ifndef::env-github[]
link:BAUTEILLISTE.html[Bauteilliste]
endif::[]

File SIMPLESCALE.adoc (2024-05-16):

// Mobile-Bienenstock-Waage, Version 2.0, Mai 2024

:imagesdir: pictures

= Mobile-Bienenstock-Waage
Achim Kraus <achim.kraus@cloudcoap.net>
v0.3, 2024-05-07

== Einfache Waage

[cols="3*"]
|===
a|.Waage mit 4 Halbbrücken
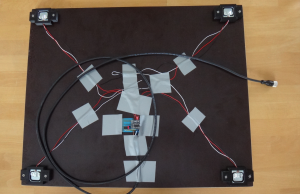
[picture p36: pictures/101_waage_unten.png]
Waage von unten
 
a|.Verkablungsschema
Waage Verkabelung 
a|.ADC Anschlußbelegung
ADC Verkabelung
|===

Die abgebildete Waage ist ein einfacher Aufbau mit 4x Halbbrücken Wägezellen für je 50Kg. Diese Wägezellen werden normalerweise für Personenwaagen benutzt.

Diese Halbbrücken Wägezellen müssen zu einer link:https://de.wikipedia.org/wiki/Wheatstonesche_Messbr%C3%BCcke[Wheatstone-Brücke] verbunden werden. Dazu verbindet man jeweils die Schwarzen und Weißen Drähte. Über die Roten werden dann ``E+``/``E-``/``A+``/``A-`` des NAU7802 verbunden, siehe Abbildung oben. Wichtig ist, das jeweils die Sensoren für ``E+`` und ``E-`` so wie ``A+`` und ``A-`` gegenüber liegen. Liegen diese nebeneinander, dann funktioniert es nicht. Verwechselt man nur ``+`` und ``-`` dann sieht man das daran, dass bei Belastung der angezeigte Wert abnimmt. Dann einach eines der ``+`` und ``-`` Paare tauschen und dann funktioniert es.

Aktuell ist die Waage ein Prototyp. Die Sensoren werden mit Kunststoffgehäusen aus dem 3D Drucker gehalten, die Kabel mit Klebebänder fixiert. Das wird sich noch ändern, wenn die Waagen sich mehr bewähren. Die ADC Platine muss auch in ein Gehäuse, sonst wird es bei Regen schnell kritisch.

Diese einfachen Sensoren sind für Personenwaagen ausgelegt, bei Dauerbelastung im Freien kommt es vor, dass man öfter die Sensore als die Batterien tauschen muss. Besonders bei sehr schweren Bienenstöcken (>> 50kg) oder wenn mit Nageschäden (Mäuse) gerechnet werden muss, funktionieren diese Sensoren eher kurz und nicht über viele Monate oder gar Jahre. Auch die Abdichtung der einfachen Sensore gegen Regen hält nicht ewig. Die Sensorhalter aus dem 3D-Drucker wurden mit link:halterung_fuer_waegezellen.stl[Halterung für Wägezellen] erstellt. Die Sensoren werden durch den Abstandshalter etwas von der Siebdruckplatten weg gehalten, was die Erwärmung durch Sonneeinstrahlung über diese Platten verringert. Trotzdem muss man bauartbedingt mit größeren Abweichungen rechnen (\+/- 1kg), wenn die Waage in der Sonne steht. Berücksichtigt man dann eine stellenweise Erwärmung (50° in der Sonne aber 25° im Schatten), dann kann diese temperaturbedingt Abweichungen nicht kompensiert werden.

Für mich hat diese Aufbau denoch seine Berechtigung. Er ist einfach und als erster Einstieg meiner Ansicht nach geeignet. Wer dann präzisere Waagen oder haltbarere Waagen möchte, kann den Aufbau der Waage später noch anpassen und die Sensoren ersetzen. Die ADC Platine, die Sendbox und die Platten der Waage bleiben die selben. Wenn man z.B. einen 
ifdef::env-github[]
link:DOUBLESCALE.adoc[Waagenaufbau mit 2 Plattform Wägezellen]
endif::[]
ifndef::env-github[]
link:DOUBLESCALE.html[Waagenaufbau mit 2 Plattform Wägezellen]
endif::[]
nimmt, dann bekommt man eine besser Genauigkeit und Haltbarkeit. Aber das hat auch seinen höheren Preis. Auf der Rückseite der NAU7802/Adafruit Platine ist übrigens angegeben, wie man die Farben der Leitungen einer Plattform Wägezelle jeweils anschließt. Das Bild oben rechts zeigt die Rückseite der NAU7802/Adafruit Platine. 

Was ich beim Basteln als besondere Herausforderung empfunden habe ist das Kalibrieren. Der eigentlich Vorgang ist im nächsten Abschnitt erläutert. Das Problem ist, dass man ein 10 kg Gewicht für eine sogenannte 2-Punkt Kalibrierung benötigt. Punkt 1 ist dann 0 kg und Punkt 2 10 kg. Wenn das absolute Gewicht nicht so wichtig ist, kann man natürlich auch einfach etwas nehmen, was in etwa 10 kg hat. Durch Temperaturschwankungen und die Dauerbelastung ist das absolute Gewicht ohnehin eher sehr relativ (da liegt man schnell 1 kg daneben) aber der Verlauf über mehrere Tage hinweg ist gut sichtbar.  

== Bauteilliste

Eine Liste mit Vorschlägen für die verwendeten Bauteilen und deren Bezugsquellen habe ich auch erstellt.
Es gibt bei den einzelnen Bauteilen Alternativen und alternative Bezugsquellen.

ifdef::env-github[]
link:BAUTEILLISTE.adoc[Bauteilliste]
endif::[]

ifndef::env-github[]
link:BAUTEILLISTE.html[Bauteilliste]
endif::[]

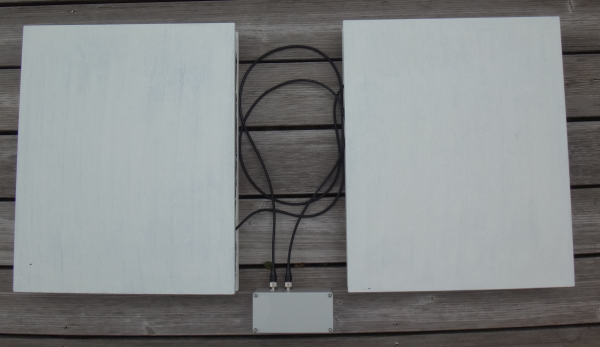
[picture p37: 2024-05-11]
pictures/205_waage_mit sendebox.png

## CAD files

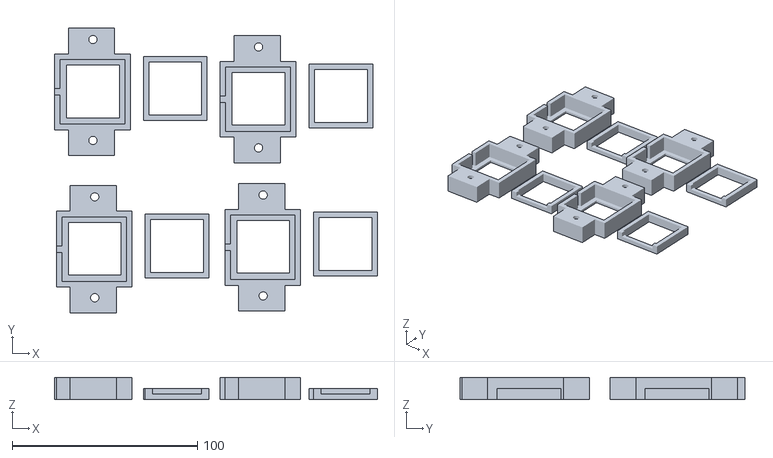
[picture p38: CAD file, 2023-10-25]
halterung_fuer_waegezellen.stl
174.5 x 154.0 x 12.0

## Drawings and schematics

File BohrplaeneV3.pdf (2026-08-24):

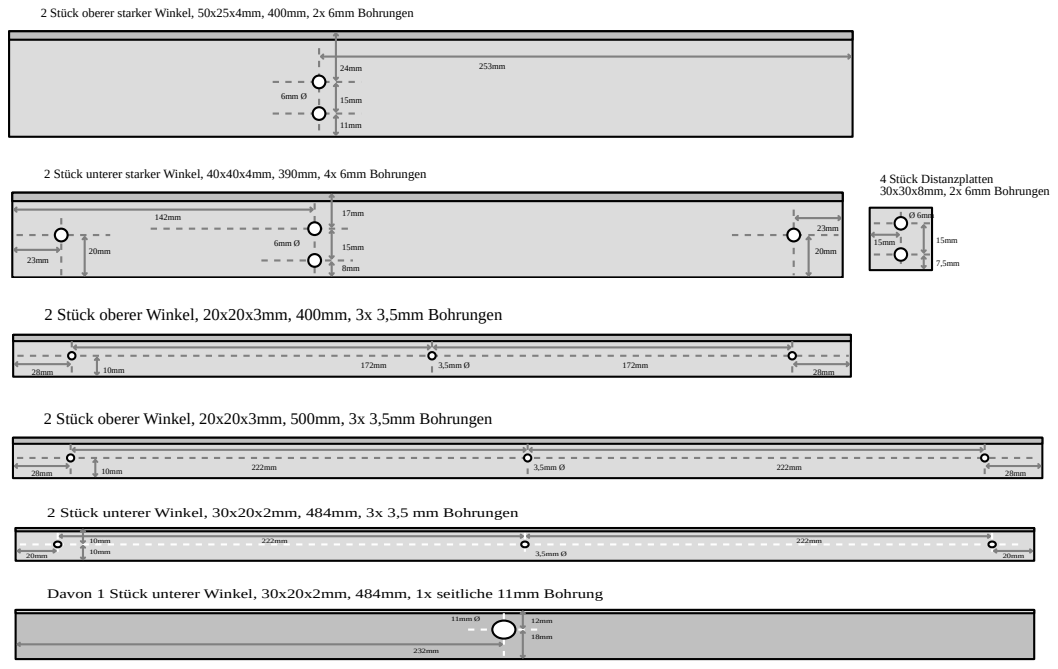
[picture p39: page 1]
4 Stück Distanzplatten 30x30x8mm, 2x 6mm Bohrungen

2 Stück oberer starker Winkel, 50x25x4mm, 400mm, 2x 6mm Bohrungen

2 Stück unterer starker Winkel, 40x40x4mm, 390mm, 4x 6mm Bohrungen

2 Stück oberer Winkel, 20x20x3mm, 400mm, 3x 3,5mm Bohrungen

2 Stück oberer Winkel, 20x20x3mm, 500mm, 3x 3,5mm Bohrungen

2 Stück unterer Winkel, 30x20x2mm, 484mm, 3x 3,5 mm Bohrungen

Davon 1 Stück unterer Winkel, 30x20x2mm, 484mm, 1x seitliche 11mm Bohrung

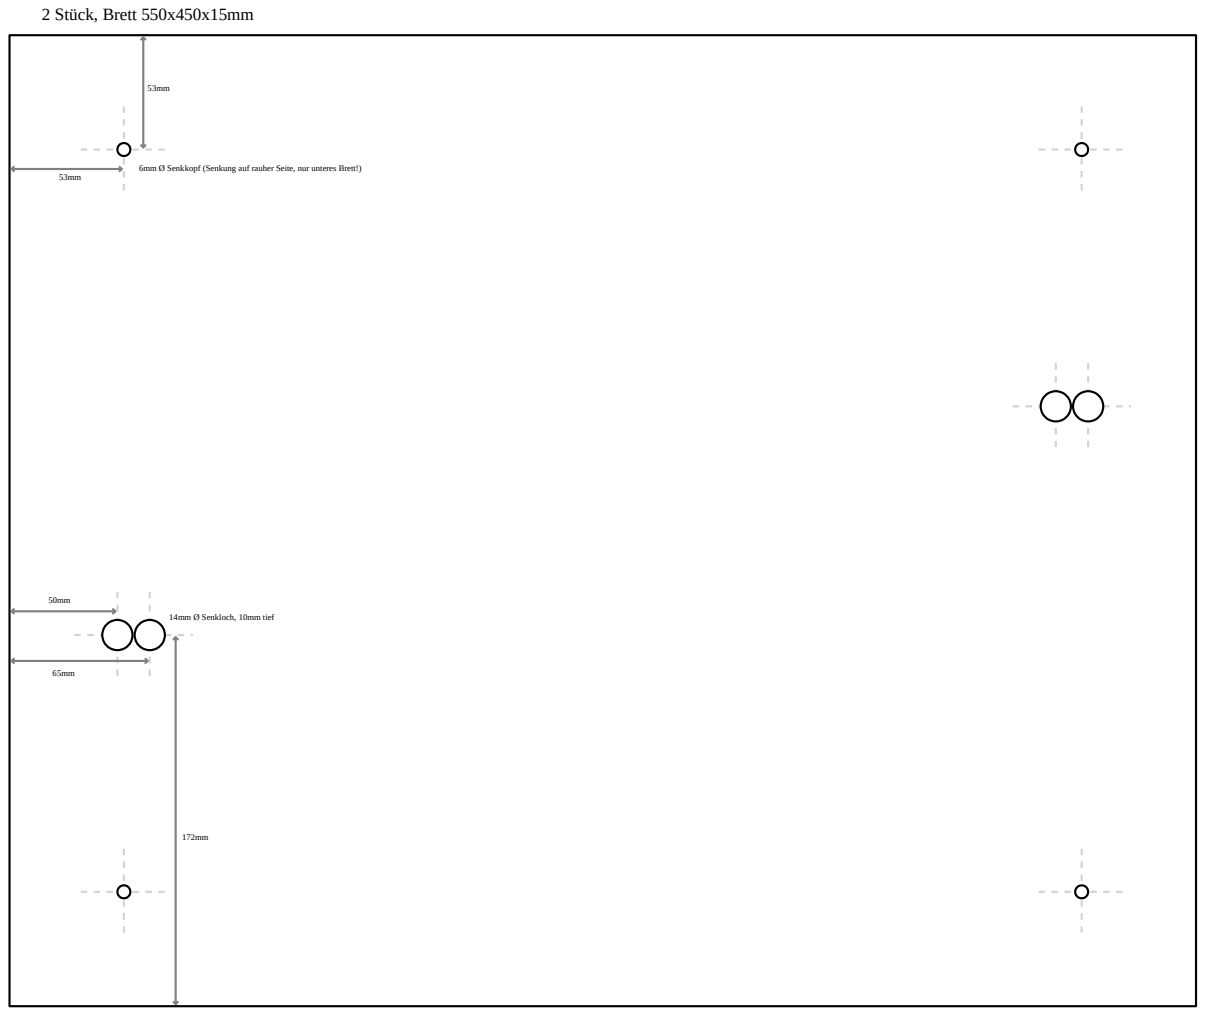
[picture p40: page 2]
2 Stück, Brett 550x450x15mm; 14mm Ø Senkloch, 10mm tief

6mm Ø Senkkopf (Senkung auf rauher Seite, nur unteres Brett!)

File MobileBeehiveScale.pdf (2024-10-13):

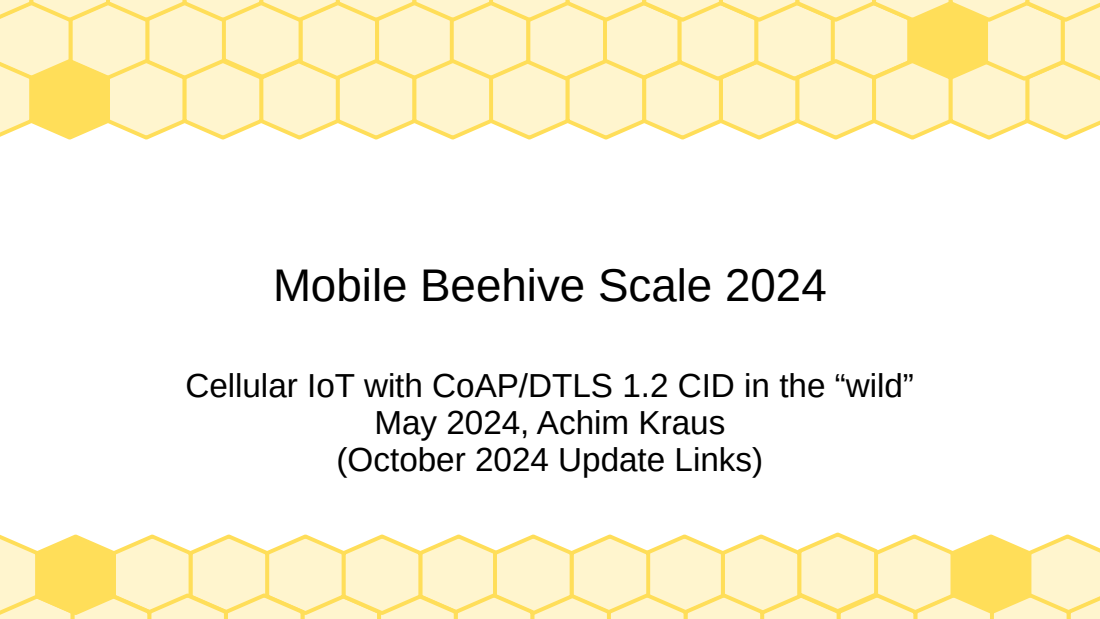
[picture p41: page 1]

Mobile Beehive Scale 2024

Cellular IoT with CoAP/DTLS 1.2 CID in the “wild”

May 2024, Achim Kraus
(October 2024 Update Links)

# Speaker

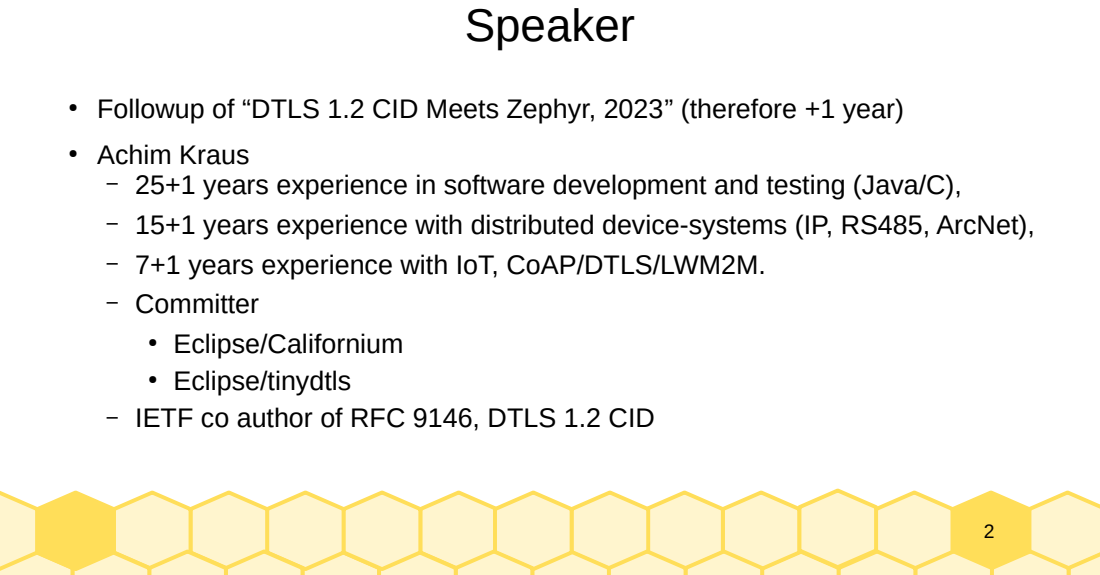
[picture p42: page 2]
● Achim Kraus; 25+1 years experience in software development and testing (Java/C),; 15+1 years experience with distributed device-systems (IP, RS485, ArcNet),; 7+1 years experience with IoT, CoAP/DTLS/LWM2M.; Committer; ● Eclipse/Californium; ● Eclipse/tinydtls; IETF co author of RFC 9146, DTLS 1.2 CID

● Followup of “DTLS 1.2 CID Meets Zephyr, 2023” (therefore +1 year)

# Contents

## - Short technical overview of the system

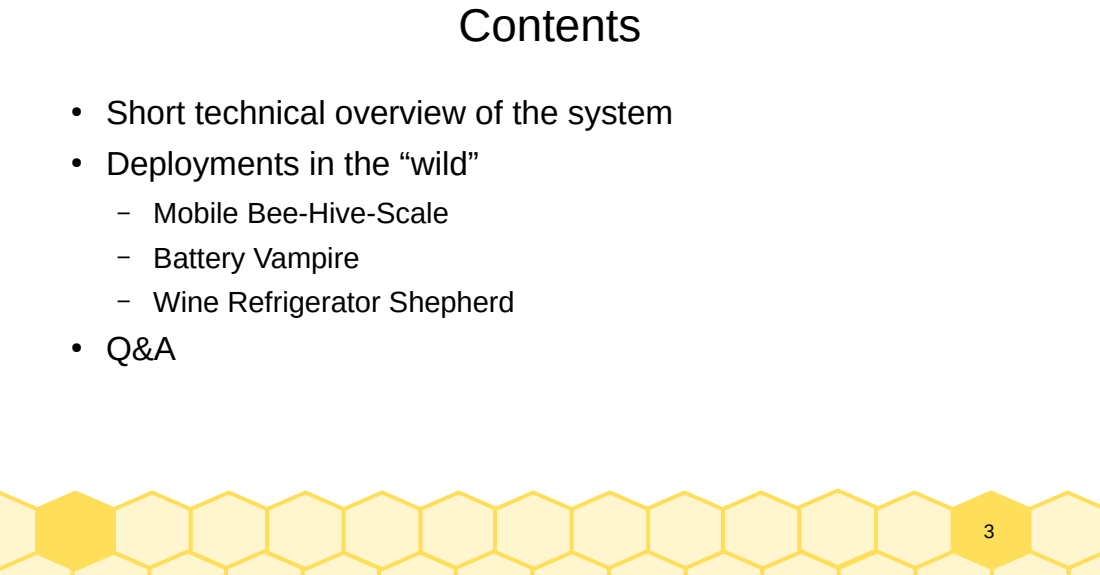
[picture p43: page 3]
Mobile Bee-Hive-Scale; Battery Vampire; Wine Refrigerator Shepherd

● Deployments in the “wild”

# CoAP-DTLS 1.2 CID

- CoAP, RFC 7252

http like REST over UDP. Efficient and reliable.

Great match for radio-messages based communication.

- DTLS 1.2 CID, RFC 6347, RFC 9146

TLS like encryption over UDP. CID (Connection ID) supporting quietphases unlocks the new power saving functions for radio messages based communication as PSM and RAI.

- Together a IETF standardized way to communicate efficient, reliable and secure over radio messages. Of course, it works on wires as well.

# Overview - Building-Blocks

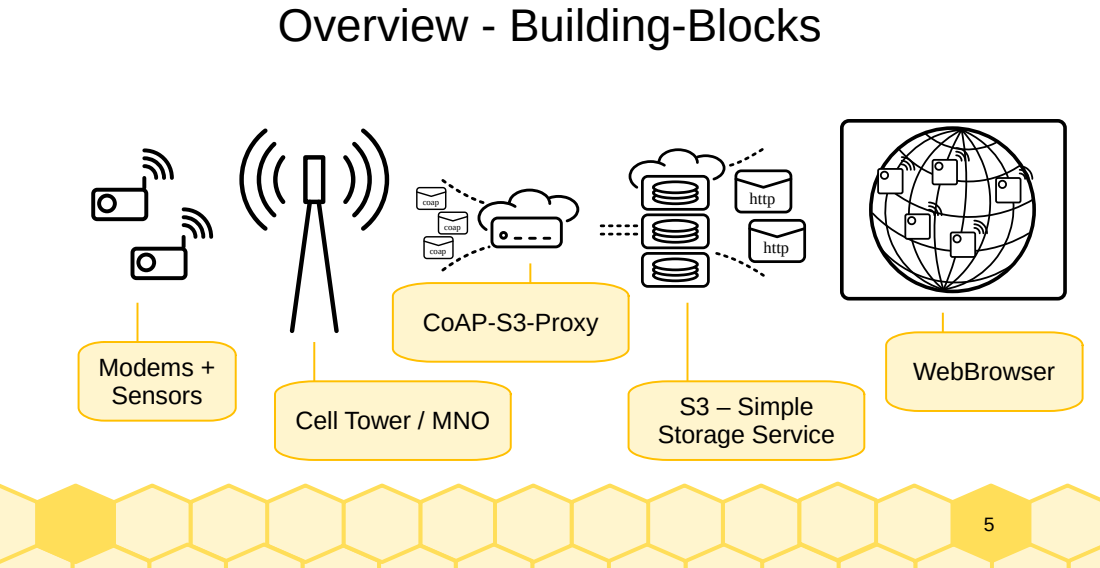
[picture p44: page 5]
Modems +; Sensors; CoAP-S3-Proxy; S3 – Simple; Storage Service; WebBrowser; coap; http

Cell Tower / MNO

# Modem

## - HW: currently nRF9160 based device are supported, see

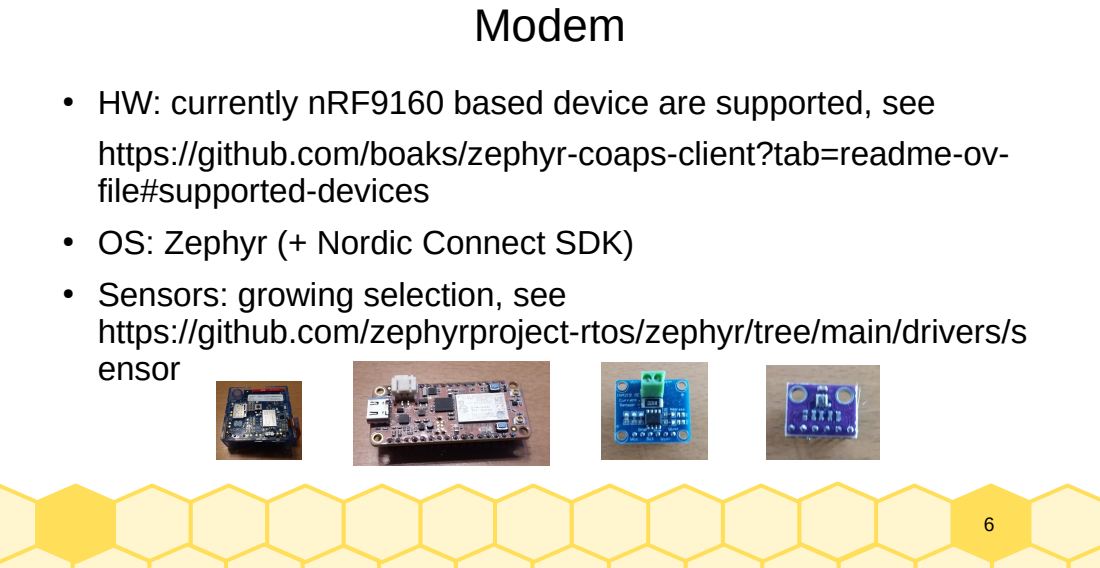
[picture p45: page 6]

https://github.com/boaks/zephyr-coaps-client?tab=readme-ov-
file#supported-devices

● OS: Zephyr (+ Nordic Connect SDK)

● Sensors: growing selection, see
https://github.com/zephyrproject-rtos/zephyr/tree/main/drivers/s
ensor

# Modem

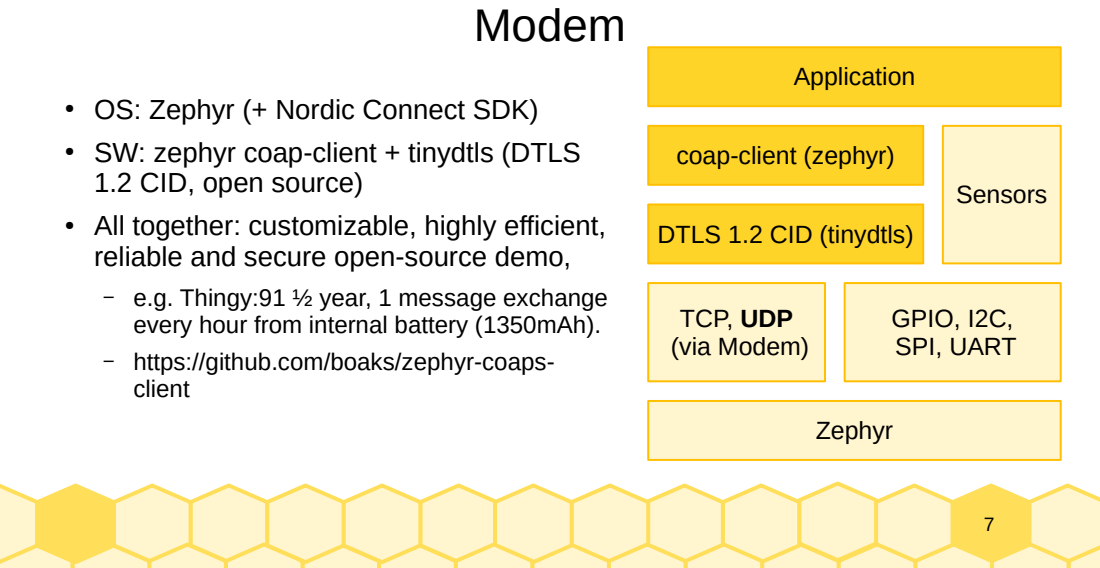
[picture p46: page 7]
e.g. Thingy:91 ½ year, 1 message exchange; https://github.com/boaks/zephyr-coaps-; client; Zephyr; GPIO, I2C,; SPI, UART; TCP, UDP; (via Modem); Application; Sensors

● OS: Zephyr (+ Nordic Connect SDK)

● SW: zephyr coap-client + tinydtls (DTLS
1.2 CID, open source)

coap-client (zephyr)

● All together: customizable, highly efficient,
reliable and secure open-source demo,

DTLS 1.2 CID (tinydtls)

every hour from internal battery (1350mAh).

# Cloud-CoAP

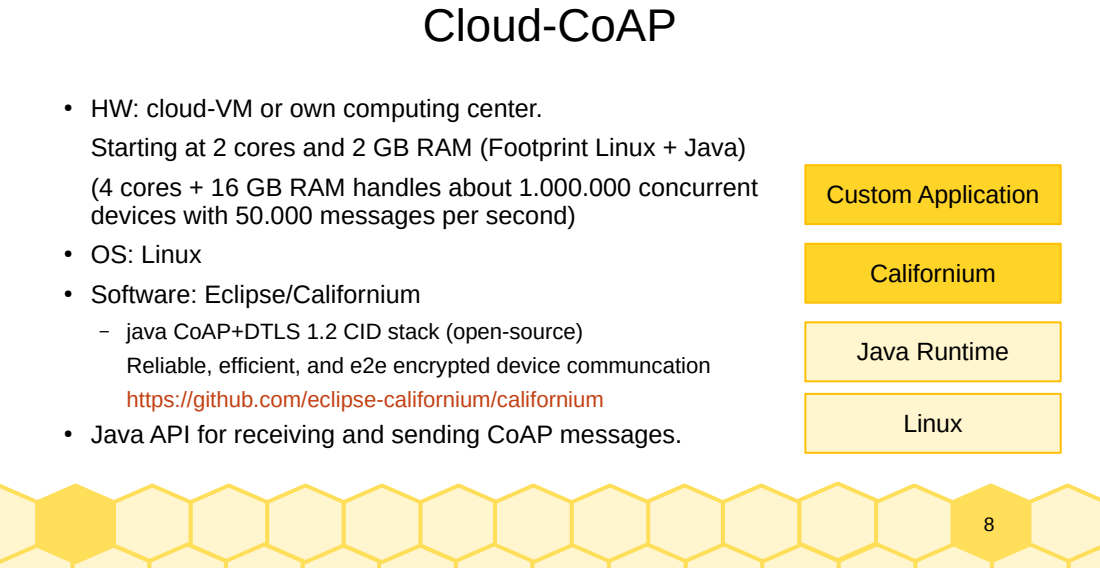
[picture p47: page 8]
● OS: Linux; java CoAP+DTLS 1.2 CID stack (open-source); Java API for receiving and sending CoAP messages.; Linux; Java Runtime; Californium; Custom Application

● HW: cloud-VM or own computing center.

Starting at 2 cores and 2 GB RAM (Footprint Linux + Java)

(4 cores + 16 GB RAM handles about 1.000.000 concurrent
devices with 50.000 messages per second)

● Software: Eclipse/Californium

Reliable, efficient, and e2e encrypted device communcation

https://github.com/eclipse-californium/californium

# Cloud-CoAP

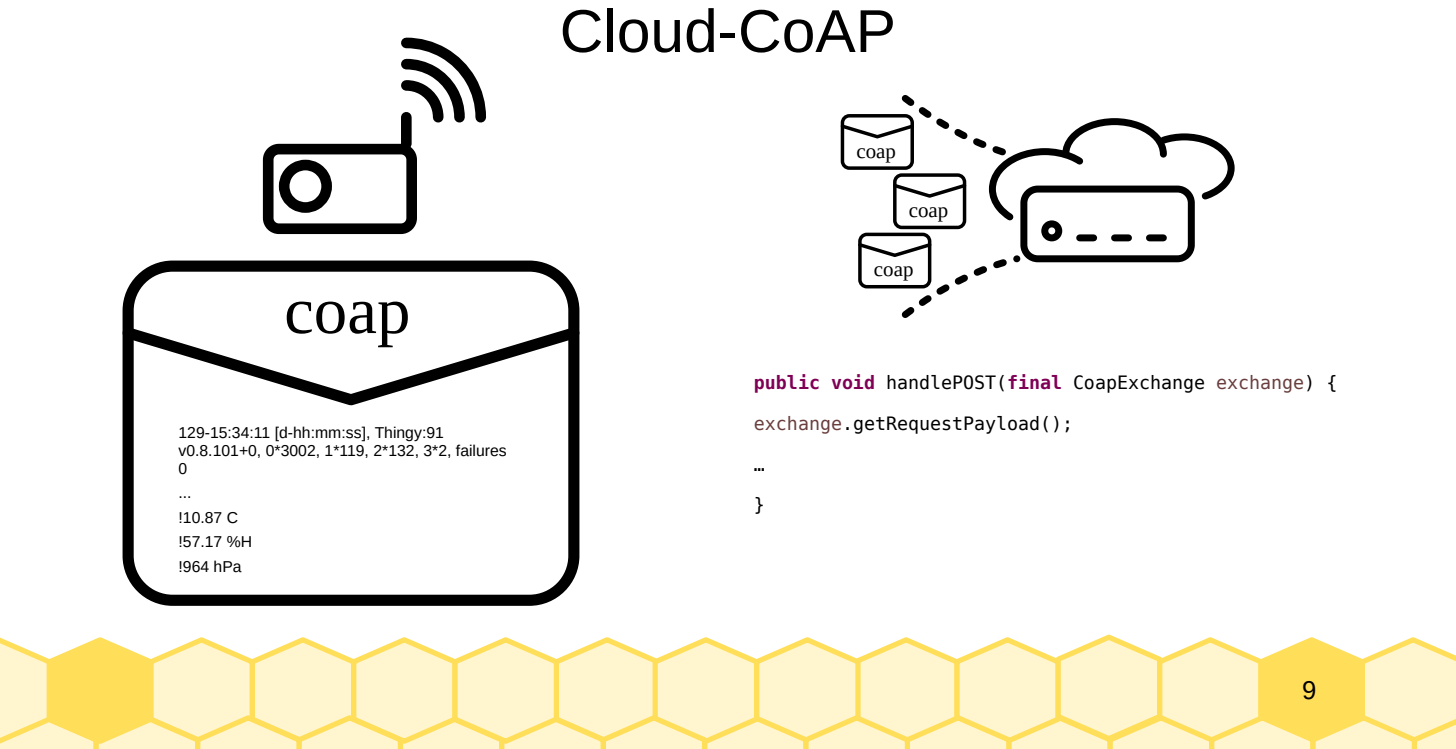
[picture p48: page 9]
!964 hPa; exchange.getRequestPayload();; coap

public void handlePOST(final CoapExchange exchange) {

129-15:34:11 [d-hh:mm:ss], Thingy:91
v0.8.101+0, 0*3002, 1*119, 2*132, 3*2, failures

# Demo Custom Application: CoAP-S3-Proxy

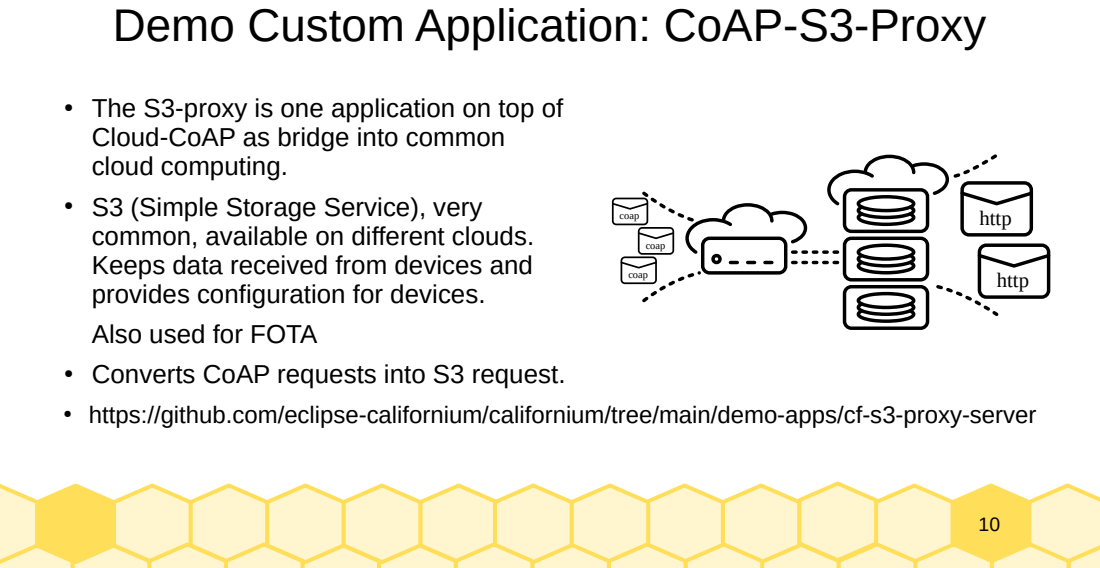
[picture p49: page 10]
coap; http

● The S3-proxy is one application on top of
Cloud-CoAP as bridge into common
cloud computing.

● S3 (Simple Storage Service), very
common, available on different clouds.
Keeps data received from devices and
provides configuration for devices.

Also used for FOTA

● Converts CoAP requests into S3 request.

● https://github.com/eclipse-californium/californium/tree/main/demo-apps/cf-s3-proxy-server

# CoAP-S3-Proxy

- S3 reduces the maximum number of messages per second (depends on S3-provider, 300-3000 messages per second and more).
- 1.000.000 devices, 1 message per hour => less than 300 messages per second.
- FOTA requires multiple CoAP request (e.g. 400 for 400KB) but 1 S3 request, there you benefit from Californium’s performance.
- Permission system for S3 is sometimes limited. Intended for backend systems, not users.
- The CoAP-S3-Proxy mitigates that by supporting multiple S3 buckets using different API-keys.
- Installation scripts for ExoScale, AWS, DigitalOcean. Or manual installation step-bystep.

# Web-Browser App

## - HW: Smart Phone, Tablet, PC

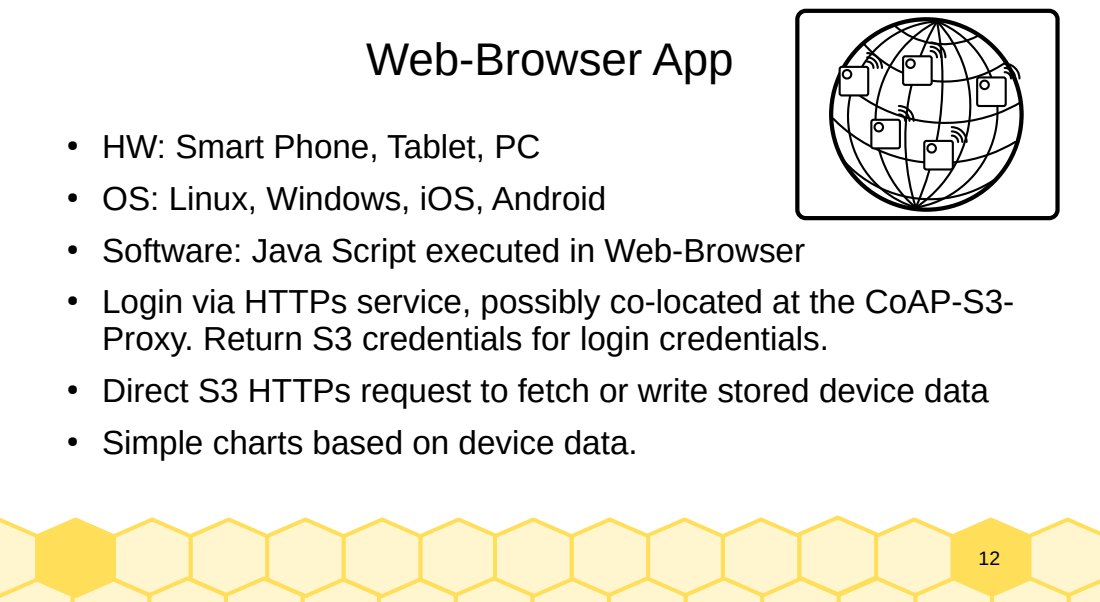
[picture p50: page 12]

● OS: Linux, Windows, iOS, Android

● Software: Java Script executed in Web-Browser

● Login via HTTPs service, possibly co-located at the CoAP-S3-
Proxy. Return S3 credentials for login credentials.

● Direct S3 HTTPs request to fetch or write stored device data

● Simple charts based on device data.

# Web-Browser App

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

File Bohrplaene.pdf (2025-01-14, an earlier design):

Gehäuse Vorderseite; Gehäuse Rückseite; Sendbox Platine

Oberer Aluwinkel, 20x20x3mm, 510mm, 2x; Unterer Aluwinkel, 20x20x3mm, 496mm, 2x

Oberer starker Aluwinkel, 25x50x5mm, 410mm, 2x

Unterer starker Aluwinkel, 30x50x5mm, 400mm, 2x

Unterer Aluwinkel, 20x20x3mm, 496mm, 1x, seitlicher 6mm Schlitz

Brett 550x450x15mm, 2x; 8mm Ø (nur unten!)

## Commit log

2023-10-25 Initial commit.
    [halterung_fuer_waegezellen.stl]
2024-03-13 Anmerkung zu I2C.
    Kleine Textänderungen bei der "double" Waage.
2024-03-13 Text für Begrenzung der Auslenkung vereinfacht.
2024-05-11 Abtrennen der Waagenanleitungen von README.
    PDF mit software system Uebersicht.
2024-05-16 ADC Beschaltung fuer Doppel ergaenzen.
2025-01-14 Laenge des unteren starken Aluwinkel korrogiert.
    396 mm unten und 410mm oben läst eine größeren Spalt bei 3mm starken
    seitlichen Winkeln.
